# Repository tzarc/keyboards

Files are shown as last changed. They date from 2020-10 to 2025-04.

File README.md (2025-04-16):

# @tzarc's Keyboards.

Here you'll find the design files for @tzarc's custom keyboard designs.

Since February 2024, licenses have changed from GPL3 to CERN-OHL-S.

## Djinn

The [Djinn](Djinn/README.md) is a 64-key split keyboard -- dual 4x7 with a 4-key thumb cluster. It also has a 5-way tactile switch under the thumb.

Djinn

## Ghoul

The [Ghoul](Ghoul/README.md) is a Planck-like development board for QMK, using SparkFun MicroMod for hot-swap MCU capability in a `2x4x5=40` layout with encoder and RGB OLED, per-key RGB.

Ghoul

## Kobold

The [Kobold](Kobold/README.md) is an ortho 4x4 macropad, as a replacement for a bm16s with modern hardware.

Kobold

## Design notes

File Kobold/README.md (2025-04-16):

# Kobold

4x4 macropad running QMK, in the same form factor as a bm16s. Non-standard Choc key spacing.

STM32G431, North-facing RGB, SPI NOR Flash, voltage and current measurement, direct pin matrix, reset to bootloader by holding top 4 keys.

Kobold

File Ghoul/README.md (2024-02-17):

# Ghoul

Planck-like development board for QMK, using SparkFun MicroMod for hot-swap MCU capability.

`2x4x5=40` layout with encoder and RGB OLED, per-key RGB.

Has hardware support for MicroSD, SPI EEPROM, SPI NOR Flash.

Uses 74HC589 SPI Shift Registers for key matrix.

Ghoul

Micromod

Top

Bottom

(images generated by [tracespace](https://tracespace.io/))

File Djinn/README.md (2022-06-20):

# Djinn Split Keyboard

The Djinn is a 64-key split keyboard -- dual 4x7 with a 4-key thumb cluster. It also has a 5-way tactile switch under the thumb.

Djinn

Extravagance-wise, it's got audio, encoder support, per-key RGB and RGB underglow... and a 240x320 LCD. And for the safety conscious, it has ESD protection, transient voltage suppression, and polarity protection on both the USB connector as well as the split transport connector (USB-C for rev2+, TRS for rev1).

It also runs [QMK Firmware](https://qmk.fm/)!

Building can be done with:

```
make tzarc/djinn/rev2:default
```

## Rev2a

BOM: [Click](Rev2a/Djinn-BOM.md)

Fixes:

* 5-way tactile moved further away from thumb row
* Different current limiters used for RGB that are actually functional in the required range

Djinn Rev2a PCB

Djinn Rev2a PCB

Djinn Rev2a Built

## Rev1

BOM: [Click](Rev1/Djinn-BOM.md)

Djinn

Issues:

* RGB current limiting has been reported to be problematic on Rev1 -- some builds have reported non-functional RGB without overriding the code to enable 1500mA limits
  * Measurements taken do not show that the RGB pulls anything close to 1500mA, unknown if there's a manufacturing issue or component selection issue
* 5-way tactile switch is too close to the thumb row in Rev1 and pressing in the down direction can't be achieved very easily

Djinn Rev1 PCB
Djinn Rev1 PCB
Djinn Rev1 PCB

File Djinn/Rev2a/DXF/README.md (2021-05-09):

# DXF Files

**! WARNING !**

**! WARNING !**

**! WARNING !**

These files are untested. They may be x1000 too large or x1000 too small.

Use at your own risk.

3D-print these if you have a printer available, before investing in carbon fibre plates or brass bases. Check geometry and sizing before spending cash.

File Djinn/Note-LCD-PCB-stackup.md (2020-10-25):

# Total Stackup

## LCD Stackup

- 3mm acrylic (or 3mm spacer)
- 4mm spacer
- 1.6mm LCD PCB
- 12mm spacer
- 1.6mm logic PCB
- **Total = 22.2mm**

| 12mm + 5mm screw     |
|----------------------|
| 3mm acrylic          |
| 4mm spacer           |
| 1.6mm LCD PCB        |
| 3.4mm of 12mm spacer |
| **= 12mm screw**     |
| 3.4mm of 12mm spacer |
| 1.6mm logic PCB      |
| **= 5mm screw**      |

---

## Plate + Logic board + Base stackup

- 1.6mm plate PCB
- 0.5mm washer
- 3mm spacer
- 1.6mm logic PCB
- 3mm spacer
- 1.6mm base PCB
- **Total = 11.3mm**

| 8mm + 3mm screw     |
|---------------------|
| 1.6mm plate PCB     |
| 3mm spacer          |
| 0.5mm washer        |
| 1.6mm logic PCB     |
| 1.3mm of 3mm spacer |
| **= 8mm screw**     |
| 1.4mm of 3mm spacer |
| 1.6mm base PCB      |
| **= 3mm screw**     |

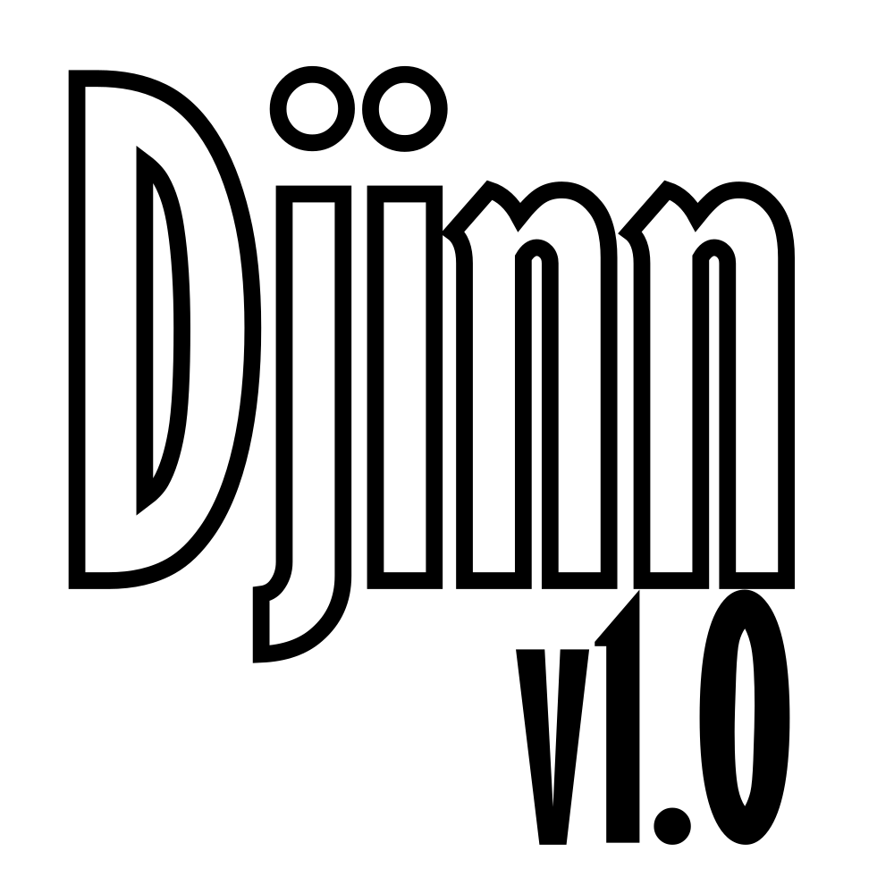
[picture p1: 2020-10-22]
Djinn/Rev1/DjinnNameVer.png

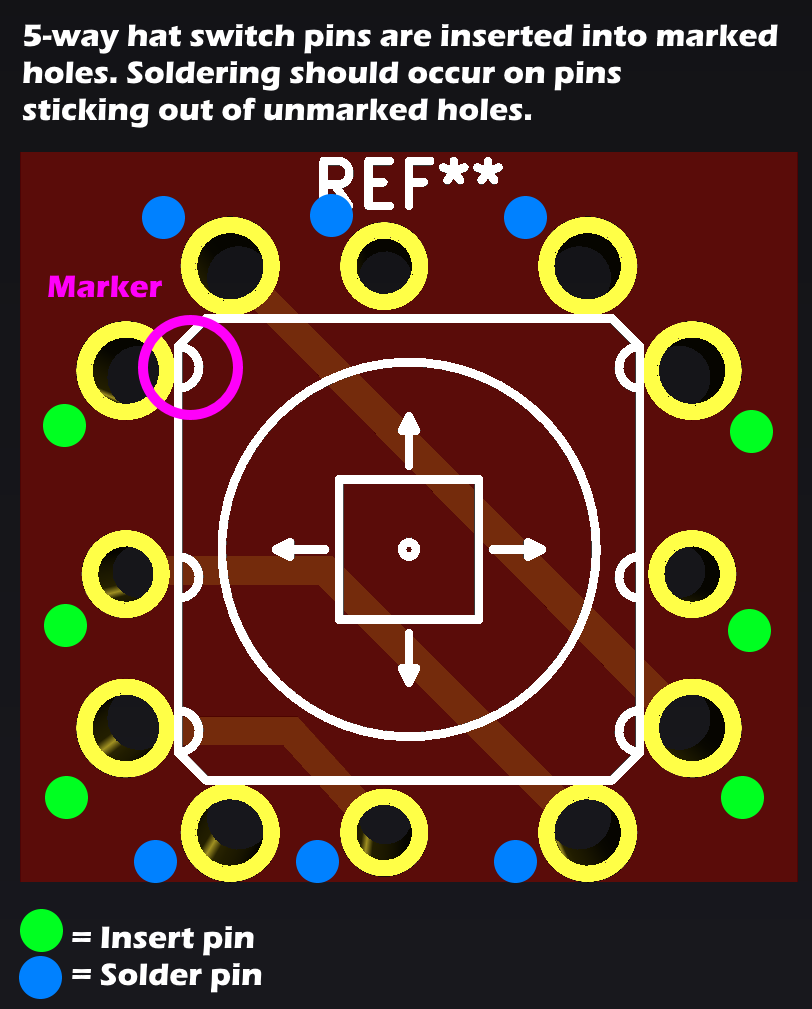
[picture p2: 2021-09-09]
Djinn/Rev2a/reversible-kicad/reversible-kicad-footprints/5Way-K1-1506DN-01.png

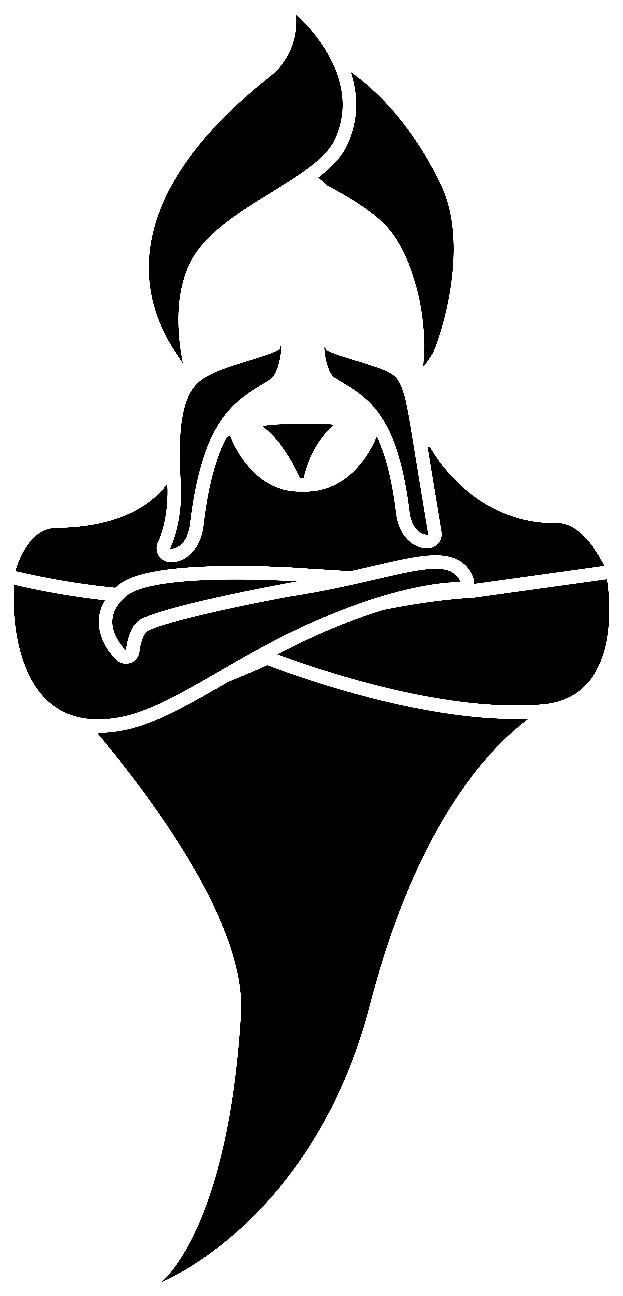
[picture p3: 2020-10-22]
Djinn/Rev1/Djinn.png

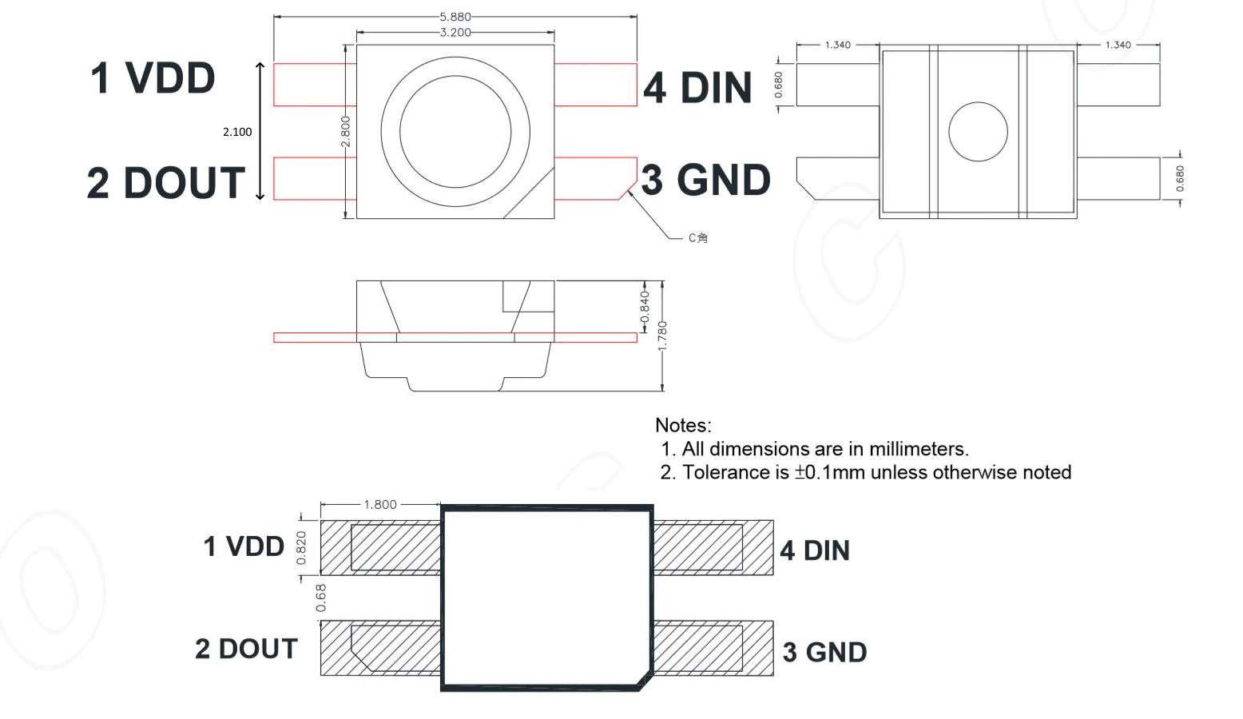
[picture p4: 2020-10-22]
Djinn/Rev1/reversible-kicad/datasheets/RGB-LED_SK6812Mini-E.png

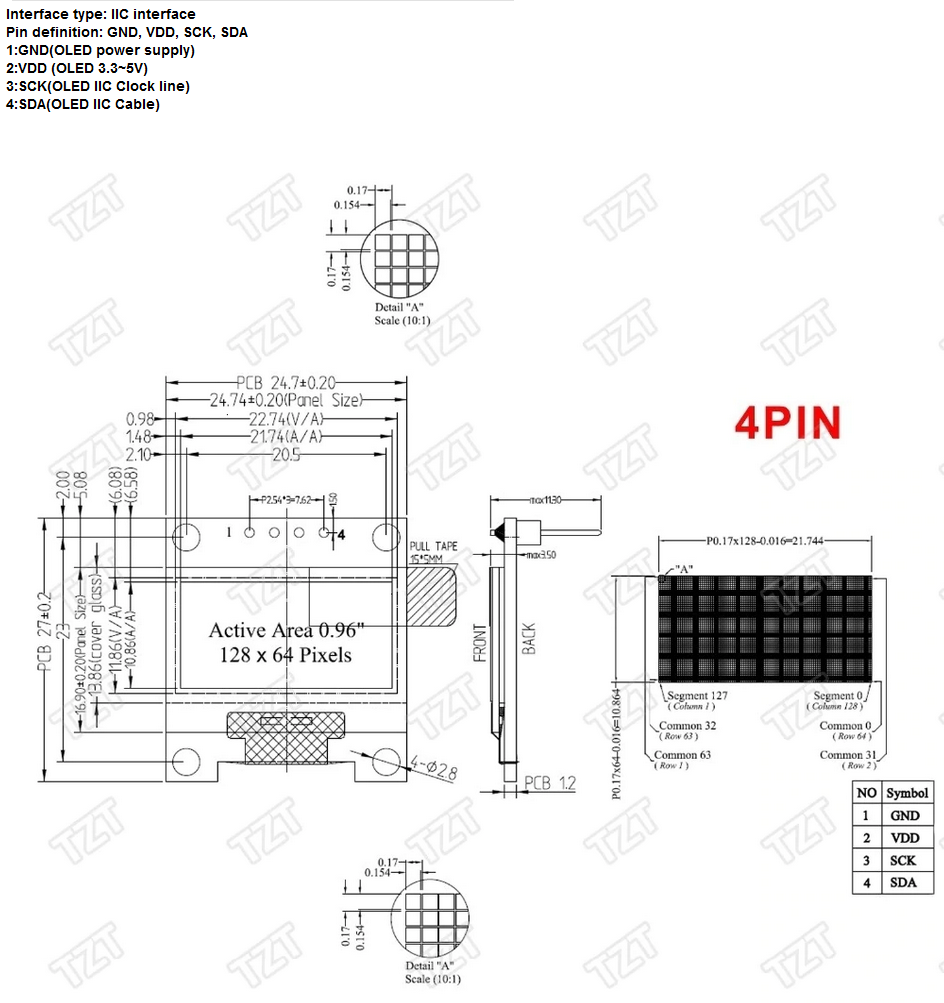
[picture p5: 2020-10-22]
Djinn/Rev1/reversible-kicad/datasheets/OLED-SSD1306-128x64.png

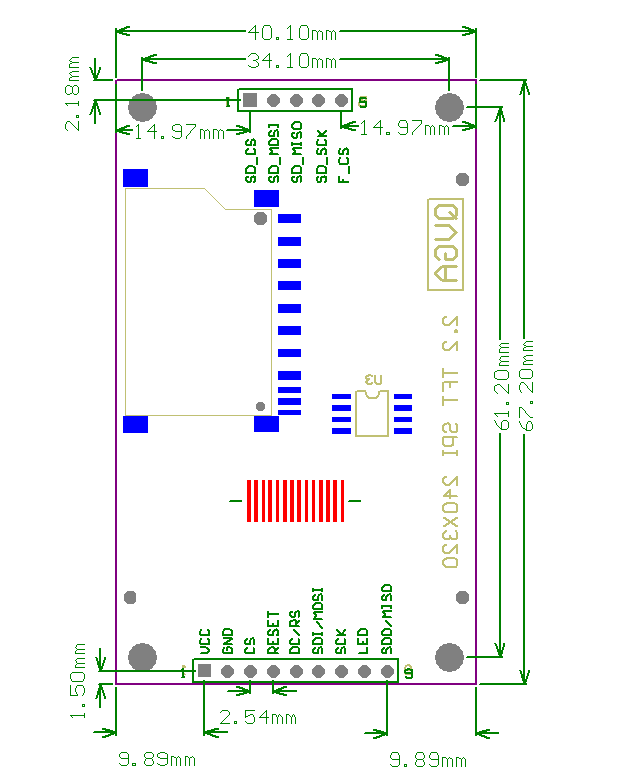
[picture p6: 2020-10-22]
Djinn/Rev1/reversible-kicad/datasheets/LCD-ILI9341-2.2in.png

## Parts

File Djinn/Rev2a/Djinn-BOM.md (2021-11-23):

# Djinn Rev2a BOM

## PCB Manufacture

I've had some reports that JLCPCB have thrown on a $15.20 USD extra charge due to too many instances of routing.

I (@tzarc) wasn't charged, but there are now reports on Discord that JLCPCB are charging extra.

If you've been given an extra charge, feel free to ask them why you've been charged more than others with the same design... and let @tzarc know so we can keep track of whether other PCB manufacturers should be recommended instead of JLCPCB.

## Build Notes

**There are two resistors that are used to determine whether the PCB is a left-hand or a right-hand board -- R23 and R25. Populate only one; R23 for a left-hand board, R25 for a right-hand board.**

During the build, the connectors for the USB-C, and the LCD 1x09 connector **need to be mounted on the side opposite to the rest of the surface-mount components**. For ease of the build, it's best to populate and solder these onto the board last. The 1x09 LCD connector can also be soldered with the LCD screwed into the board with standoffs, in order to ensure proper alignment.

RGB underglow LEDs can be soldered on either side of the board.

Most "jellybean" components can be swapped out for whichever you've got available -- 100nF capacitors are so ubiquitous that there's no need to buy this specific part. Any other 0805 100nF capacitor will likely suffice.

The "Connector (ST-Link)" **is optional** and is not required -- this is a debugging port for an ST-Link. If you choose to do so, it can be mounted with the pins straddling the edge of the PCB.

The "IC (SPI FLASH)" **is not required** -- this is for future QMK development and the Djinn has no requirement for it to be on the board.

There is a few sets of solder bridges that need to be filled in to get certain aspects working:

* LCD_Left / LCD_Right -- 9 separate solder bridges that connect the LCD connector to the normal lines required to actually drive the LCD. You'll note that these are populated in the same location on both sides of the board -- only the side being built should have the solder bridges filled in. Left-hand should have LCD_Left soldered, right-hand should have LCD_Right soldered.

## Components listing

| Type | Count (Total) | Count (Per PCB) | Value | Footprint | Part Number | Link |
|---|---|---|---|---|---|---|
| Capacitor (MLCC) | 30 | 15 | 100nF | 0805 | CL21F104ZBCNNNC | https://lcsc.com/product-detail/Multilayer-Ceramic-Capacitors-MLCC-SMD-SMT_Samsung-Electro-Mechanics-CL21F104ZBCNNNC_C1760.html |
| Capacitor (MLCC) | 8 | 4 | 4.7uF | 0805 | CL21A475KAQNNNE | https://lcsc.com/product-detail/Multilayer-Ceramic-Capacitors-MLCC-SMD-SMT_Samsung-Electro-Mechanics-CL21A475KAQNNNE_C1779.html |
| Capacitor (Tantalum) | 16 | 8 | 100uF | 6032 | F931C107KCC | https://lcsc.com/product-detail/Tantalum-Capacitors_AVX-F931C107KCC_C273664.html |
| Resistor | 36 | 18 | 9.1k 1% | 0805 | RK73H2ATTD9101F | https://lcsc.com/product-detail/Chip-Resistor-Surface-Mount_KOA-Speer-Elec-RK73H2ATTD9101F_C317276.html |
| Resistor | 22 | 11 | 68k 1% | 0805 | AC0805FR-0768KL | https://lcsc.com/product-detail/Chip-Resistor-Surface-Mount_YAGEO-AC0805FR-0768KL_C228958.html |
| Resistor | 6 | 3 | 120ohm 1% | 0805 | WR08X1200FTL | https://lcsc.com/product-detail/Chip-Resistor-Surface-Mount_Walsin-Tech-Corp-WR08X1200FTL_C163960.html |
| Diode (Signal) | 80 | 40 | 1N4148 | SOD-123FL | 1N4148WL | https://lcsc.com/product-detail/Switching-Diode_Shandong-Jingdao-Microelectronics-1N4148WL_C108804.html |
| Diode (TVS Protection)  | 4 | 2 | SMF5.0CA | SOD-123FL | SMF5.0CA | https://lcsc.com/product-detail/TVS_MDD-Microdiode-Electronics-SMF5-0CA_C364279.html |
| IC (SPI FRAM) | 2 | 1 | 64kbit/8kB | SOIC-8 | MB85RS64PNF-G-JNERE1 | https://lcsc.com/product-detail/FRAM_FUJITSU-MB85RS64PNF-G-JNERE1_C8741.html |
| IC (SPI FLASH) | 2 (skip) | 1 (skip) | - | SOIC-8W | W25Q32JVSSIQ | Not required for Djinn, do not populate, used for future QMK development |
| IC (Voltage Regulator)  | 2 | 1 | 3.3V | SOT-23-5  | AP2127K-3.3TRG1 | https://lcsc.com/product-detail/Dropout-Regulators-LDO_Diodes-Incorporated-AP2127K-3-3TRG1_C156285.html |
| IC (Op-Amp) | 2 | 1 | - | SOT-23-5  | LMV321B-TR or LMV321 | https://lcsc.com/product-detail/Low-Power-OpAmps_3PEAK-LMV321B-TR_C248567.html or https://lcsc.com/product-detail/Low-Power-OpAmps_IDCHIP-LMV321_C395459.html |
| IC (Current Limiter) | 4 | 2 | - | SOT-23-6  | TPS2553DBVR or AP2553W6-7 | https://lcsc.com/product-detail/PMIC-Power-Distribution-Switches_Texas-Instruments-TPS2553DBVR_C55266.html or https://lcsc.com/product-detail/PMIC-Power-Distribution-Switches_Diodes-Incorporated_AP2553W6-7_Diodes-Incorporated-AP2553W6-7_C212302.html |
| Diode (ESD Protection)  | 4 | 2 | - | SOT-23-6  | AZC199-04S.R7G or SRV0504 | https://lcsc.com/product-detail/TVS_AMAZING-AZC199-04S-R7G_C356821.html or https://lcsc.com/product-detail/TVS_Leiditech-SRV0504_C384888.html |
| IC (MCU) | 2 | 1 | - | LQFP-64 | STM32G474RET6 | https://au.mouser.com/ProductDetail/STMicroelectronics/STM32G474RET6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 |
| Resettable Fuse | 2 | 1 | 3.0A | 1206 | MF-NSMF150-2 | https://lcsc.com/product-detail/PTC-Resettable-Fuses_BOURNS-MF-NSMF150-2_C89655.html |
| Resettable Fuse | 2 | 1 | 1.5A | 1206 | MF-NSMF075-2 | https://lcsc.com/product-detail/PTC-Resettable-Fuses_BOURNS-MF-NSMF075-2_C89653.html |
| Switch (Hotswap Socket) | 64 | 32 | - | - | Kailh Hotswap | https://www.aliexpress.com/item/32903471019.html |
| Switch (5-way Tactile)  | 2 | 1 | - | 10x10mm | K1-1506DN-01 | https://lcsc.com/product-detail/5-way-Tactile-Switches_Korean-Hroparts-Elec-K1-1506DN-01_C145911.html |
| Switch (Cap) | 2 | 1 | - | - | 6JBLK | https://lcsc.com/product-detail/Switch-accessories-or-Caps_E-Switch-6JBLK_C273384.html |
| Switch (Rotary Encoder) | 2 | 1 | - | - | EC11N1525404 | https://lcsc.com/product-detail/Coded-Rotary-Switches_ALPS-Electric-EC11N1525404_C470748.html |
| Connector (USB-C) | 4 | 2 | - | - | TYPE-C-31-M-12 | https://lcsc.com/product-detail/USB-Connectors_Korean-Hroparts-Elec-TYPE-C-31-M-12_C165948.html |
| Inductor | 26 | 13 | 100ohm @ 100MHz 4A | 0805 | MPZ2012S101AT000 | https://lcsc.com/product-detail/Ferrite-Beads_TDK-MPZ2012S101AT000_C15957.html |
| Connector (LCD) | 2 | 1 | - | 1x09 | C39576 | https://lcsc.com/product-detail/Pin-Header-Female-Header_BOOMELE-Boom-Precision-Elec-C39576_C39576.html |
| Piezo Buzzer | 2 | 1 | - | 16x16mm | KLJ-1625 | https://lcsc.com/product-detail/Buzzers_KELIKING-KLJ-1625_C201041.html |
| Switch (Microswitch) | 2 | 1 | - | - | TSA451G50-250 | https://lcsc.com/product-detail/Tactile-Switches_BRIGHT-TSA451G50-250_C294483.html |
| RGB LED | 86 | 43 | - | 6028 | SK6812Mini-E | https://www.aliexpress.com/item/4000475685852.html |
| MOSFET | 8 | 4 | - | SOT-23-3  | AO3401A | https://lcsc.com/product-detail/MOSFET_UMW-Youtai-Semiconductor-Co-Ltd-AO3401A_C347476.html |
| MOSFET | 4 | 2 | - | SOT-23-3  | 2N7002 | https://lcsc.com/product-detail/MOSFET_MDD-Microdiode-Electronics-2N7002_C472906.html |
| Transistor (Pre-biased) | 2 | 1 | - | SOT-23-3  | MMUN2133LT1G | https://lcsc.com/product-detail/Digital-Transistors_ON-Semiconductor-MMUN2133LT1G_C86182.html |
| Transistor (Pre-biased) | 2 | 1 | - | SOT-23-3  | MMUN2233LT1G | https://lcsc.com/product-detail/Transistors-NPN-PNP_ON-Semiconductor-MMUN2233LT1G_C86932.html |
| Connector (ST-Link) | 2 (optional)  | 1 (optional) | - | 2x05 | MTF185-205SY3 | https://lcsc.com/product-detail/Pin-Header-Female-Header_MINTRON-MTF185-205SY3_C358738.html |
| LCD | 2 | 1 | - | 1x09 | 2.2" No Touch | https://www.aliexpress.com/item/4000219159401.html |

## Fasteners / Hardware

| Type | Count (Total) | Count (Per side) | Model | Link |
|---|---|---|---|---|
| Knob (Rotary Encoder) | 2 | 1 | 25x15.5x6mm  | https://www.aliexpress.com/item/32802067713.html |
| Screw | 26 | 13 | M3x3 D7x0.7  | https://www.aliexpress.com/item/32998579840.html |
| Screw | 26 | 13 | M3x8 D7x0.7  | https://www.aliexpress.com/item/32998579840.html |
| Screw | 8 | 4 | M3x12 D7x0.7 | https://www.aliexpress.com/item/32998579840.html |
| Screw | 8 | 4 | M3x5 D7x0.7  | https://www.aliexpress.com/item/32998579840.html |
| Standoff | 52 (or 60) | 26 (or 30) | M3x3x4.2 | https://www.aliexpress.com/item/4000153040875.html |
| Standoff | 8 | 4 | M3x12x4.2 | https://www.aliexpress.com/item/4000153040875.html |
| Standoff | 8 | 4 | M3x4x4.2 | https://www.aliexpress.com/item/4000153040875.html |
| Washer | 26 | 13 | M3 | https://www.aliexpress.com/item/33000267180.html |

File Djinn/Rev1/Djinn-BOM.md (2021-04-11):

# Djinn Rev1 BOM

## Build Notes

During the build, the connectors for the USB-C, the TRS jack, and the LCD 1x09 connector **need to be mounted on the side opposite to the rest of the surface-mount components**. For ease of the build, it's best to populate and solder these onto the board last. The 1x09 LCD connector can also be soldered with the LCD screwed into the board with standoffs, in order to ensure proper alignment.

Most "jellybean" components can be swapped out for whichever you've got available -- 100nF capacitors are so ubiquitous that there's no need to buy this specific part. Any other 0805 100nF capacitor will likely suffice.

The "IC (Current Limiter)" chip has two alternatives that perform the same function, with the same pinout, and are drop-in replacements of each other. Depending on stock levels at LCSC, one might not be available (as was the case when the Djinn was designed), so either can be used. Please only purchase one type -- you don't need both. These chips do have poor performance at low currents, i.e. the standard <500mA USB current range. As a result, if you push the LEDs too hard (full white, for instance) they'll flicker and sometimes "brown out" -- this is 100% intentional and is not a sign that something is wrong with your build -- this is a safety mechanism to prevent pulling too much current from the USB port. Sane limits have already been set in firmware to prevent over-current scenarios. In future, once the firmware matures, the limit will be dynamically controlled based on the USB-C power delivery state -- this is not yet implemented, but the hardware has been designed to do so.

The "Connector (ST-Link)" **is optional** and is not required -- this is a debugging port for an ST-Link. If you choose to do so, it can be mounted with the pins straddling the edge of the PCB.

There are a few sets of solder bridges that need to be filled in to get certain aspects working:

* USB-C CC Line solder bridges (solder none or one pair only):
    * (Optional) 5.1k -- 2 separate solder bridges that connect 5.1k resistors to the USB-C CC lines in order to "ask" for 3.0A from the upstream port. This is not guaranteed to automatically allow 3.0A of current, and the firmware will eventually deal with this correctly.
    * (Optional) USBPD -- 2 separate solder bridges that connect the MCU to the USB-C CC lines in order to enable USBPD functionality. This is not yet built into the firmware and for all intents and purposes should not be assumed to work. Leave these unsoldered unless you know exactly what you're doing.
    * If neither of the above pairs of solder bridges have been soldered, the Djinn will work in standard USB2.0 mode without attempting to run at a higher current than 500mA.
* LCD_Left / LCD_Right -- 9 separate solder bridges that connect the LCD connector to the normal lines required to actually drive the LCD. You'll note that these are populated in the same location on both sides of the board -- only the side being built should have the solder bridges filled in. Left-hand should have LCD_Left soldered, right-hand should have LCD_Right soldered.

## Components listing

| Type | Count (Total) | Count (Per PCB) | Value | Footprint | Part Number | Link |
|---|---|---|---|---|---|---|
| Capacitor (MLCC) | 110 | 55 | 100nF | 0805 | CL21F104ZBCNNNC | https://lcsc.com/product-detail/Multilayer-Ceramic-Capacitors-MLCC-SMD-SMT_Samsung-Electro-Mechanics-CL21F104ZBCNNNC_C1760.html |
| Capacitor (MLCC) | 2 | 1 | 4.7nF | 0805 | CC0805KRX7R9BB472 | https://lcsc.com/product-detail/Multilayer-Ceramic-Capacitors-MLCC-SMD-SMT_YAGEO-CC0805KRX7R9BB472_C107153.html |
| Capacitor (Tantalum) | 8 | 4 | 10uF | 3216 | TC212A106K016Y | https://lcsc.com/product-detail/Tantalum-Capacitors_Sunlord-TC212A106K016Y_C108529.html |
| Connector (LCD) | 2 | 1 | - | 1x09 | C39576 | https://lcsc.com/product-detail/Pin-Header-Female-Header_BOOMELE-Boom-Precision-Elec-C39576_C39576.html |
| Connector (ST-Link, *optional*) | 2 | 1 | - | 1x09 | MTF185-205SY3 | https://lcsc.com/product-detail/Pin-Header-Female-Header_MINTRON-MTF185-205SY3_C358738.html |
| Connector (TRS) | 2 | 1 | - | - | PJ-3136-B | https://lcsc.com/product-detail/Audio-Video-Connectors_XKB-Connectivity-PJ-3136-B_C381131.html |
| Connector (USB-C) | 2 | 1 | - | - | TYPE-C-31-M-12 | https://lcsc.com/product-detail/USB-Connectors_Korean-Hroparts-Elec-TYPE-C-31-M-12_C165948.html |
| Diode (ESD Protection) | 4 | 2 | USBLC6-4SC6 | SOT-23-6  | USBLC6-4SC6 | https://lcsc.com/product-detail/Diodes-ESD_STMicroelectronics_USBLC6-4SC6_USBLC6-4SC6_C111212.html |
| Diode (Schottky) | 2 | 1 | SS34 | SOD-123FL | DSS34 | https://lcsc.com/product-detail/Schottky-Barrier-Diodes-SBD_BORN-DSS34_C511866.html |
| Diode (Signal) | 80 | 40 | 1N4148 | SOD-123FL | 1N4148WL | https://lcsc.com/product-detail/Switching-Diode_Shandong-Jingdao-Microelectronics-1N4148WL_C108804.html |
| Diode (TVS Protection) | 4 | 2 | SMF5.0CA | SOD-123FL | SMF5.0CA | https://lcsc.com/product-detail/TVS_MDD-Microdiode-Electronics-SMF5-0CA_C364279.html |
| IC (Current Limiter) | 2 | 1 | - | SOT-23-5  | MT9700 *or* DIO7002  | https://lcsc.com/product-detail/PMIC-Power-Distribution-Switches_MT9700_C89855.html *or* https://lcsc.com/product-detail/PMIC-Power-Distribution-Switches_DIOO-DIO7002AST5_C403840.html |
| IC (MCU) | 2 | 1 | - | LQFP-64 | STM32G474RET6 | https://au.mouser.com/ProductDetail/STMicroelectronics/STM32G474RET6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 |
| IC (SPI FRAM) | 2 | 1 | 64kbit/8kB  | SOIC-8 | MB85RS64PNF-G-JNERE1 | https://lcsc.com/product-detail/FRAM_FUJITSU-MB85RS64PNF-G-JNERE1_C8741.html |
| IC (Voltage Regulator) | 2 | 1 | 3.3V | SOT-23-5  | AP2127K-3.3TRG1 | https://lcsc.com/product-detail/Dropout-Regulators-LDO_Diodes-Incorporated-AP2127K-3-3TRG1_C156285.html |
| LCD | 2 | 1 | - | 1x09 | 2.2" No Touch | https://www.aliexpress.com/item/4000219159401.html |
| MOSFET | 6 | 3 | - | SOT-23-3  | AO3401A | https://lcsc.com/product-detail/MOSFET_UMW-Youtai-Semiconductor-Co-Ltd-AO3401A_C347476.html |
| Piezo Buzzer | 2 | 1 | - | 16x16mm | KLJ-1625 | https://lcsc.com/product-detail/Buzzers_KELIKING-KLJ-1625_C201041.html |
| Resettable Fuse | 2 | 1 | 1.5A | 1206 | MF-NSMF075-2 | https://lcsc.com/product-detail/PTC-Resettable-Fuses_BOURNS-MF-NSMF075-2_C89653.html |
| Resettable Fuse | 2 | 1 | 3.0A | 1206 | MF-NSMF150-2 | https://lcsc.com/product-detail/PTC-Resettable-Fuses_BOURNS-MF-NSMF150-2_C89655.html |
| Resistor | 2 | 1 | 1.5k 1% | 0805 | RC0805FR-071K5L | https://lcsc.com/product-detail/Chip-Resistor-Surface-Mount_YAGEO-RC0805FR-071K5L_C114555.html |
| Resistor | 2 | 1 | 100k 1% | 0805 | 0805W8F1003T5E | https://lcsc.com/product-detail/Chip-Resistor-Surface-Mount_UNI-ROYAL-Uniroyal-Elec-0805W8F1003T5E_C149504.html |
| Resistor | 2 | 1 | 13.7k 1% | 0805 | CR0805F81372G | https://lcsc.com/product-detail/Chip-Resistor-Surface-Mount_LIZ-Elec-CR0805F81372G_C101466.html |
| Resistor | 2 | 1 | 52.3k 1% | 0805 | WR08X5232FTL | https://lcsc.com/product-detail/Chip-Resistor-Surface-Mount_Walsin-Tech-Corp-WR08X5232FTL_C170927.html |
| Resistor | 20 | 10 | 9.1k 1% | 0805 | RK73H2ATTD9101F | https://lcsc.com/product-detail/Chip-Resistor-Surface-Mount_KOA-Speer-Elec-RK73H2ATTD9101F_C317276.html |
| Resistor | 4 | 2 | 120ohm 1% | 0805 | WR08X1200FTL | https://lcsc.com/product-detail/Chip-Resistor-Surface-Mount_Walsin-Tech-Corp-WR08X1200FTL_C163960.html |
| Resistor | 4 | 2 | 1M 1% | 0805 | 0805W8F1004T5E | https://lcsc.com/product-detail/Chip-Resistor-Surface-Mount_UNI-ROYAL-Uniroyal-Elec-0805W8F1004T5E_C17514.html |
| Resistor | 8 | 4 | 5.1k 1% | 0805 | 0805W8F5101T5E | https://lcsc.com/product-detail/Chip-Resistor-Surface-Mount_UNI-ROYAL-Uniroyal-Elec-0805W8F5101T5E_C27834.html |
| RGB LED | 84 | 42 | - | 6028 | SK6812Mini-E | https://www.aliexpress.com/item/4000475685852.html |
| Switch (5-way Tactile) | 2 | 1 | - | 10x10mm | K1-1506DN-01 | https://lcsc.com/product-detail/5-way-Tactile-Switches_Korean-Hroparts-Elec-K1-1506DN-01_C145911.html |
| Switch (Cap) | 2 | 1 | - | - | 6JBLK | https://lcsc.com/product-detail/Switch-accessories-or-Caps_E-Switch-6JBLK_C273384.html |
| Switch (Hotswap Socket) | 64 | 32 | - | - | Kailh Hotswap | https://www.aliexpress.com/item/32903471019.html |
| Switch (Microswitch) | 2 | 1 | - | - | TSA451G50-250 | https://lcsc.com/product-detail/Tactile-Switches_BRIGHT-TSA451G50-250_C294483.html |
| Switch (Rotary Encoder) | 2 | 1 | - | - | EC11N1525404 | https://lcsc.com/product-detail/Coded-Rotary-Switches_ALPS-Electric-EC11N1525404_C470748.html |
| Transistor (Pre-biased) | 2 | 1 | - | SOT-23-3  | MMUN2133LT1G | https://lcsc.com/product-detail/Digital-Transistors_ON-Semiconductor-MMUN2133LT1G_C86182.html |
| Transistor (Pre-biased) | 6 | 3 | - | SOT-23-3  | MMUN2233LT1G | https://lcsc.com/product-detail/Transistors-NPN-PNP_ON-Semiconductor-MMUN2233LT1G_C86932.html |

## Fasteners / Hardware

| Type | Count (Total) | Count (Per side) | Model | Link |
|---|---|---|---|---|
| Knob (Rotary Encoder) | 2 | 1 | 25x15.5x6mm  | https://www.aliexpress.com/item/32802067713.html |
| Screw | 26 | 13 | M3x3 D7x0.7  | https://www.aliexpress.com/item/32998579840.html |
| Screw | 26 | 13 | M3x8 D7x0.7  | https://www.aliexpress.com/item/32998579840.html |
| Screw | 8 | 4 | M3x12 D7x0.7 | https://www.aliexpress.com/item/32998579840.html |
| Screw | 8 | 4 | M3x5 D7x0.7  | https://www.aliexpress.com/item/32998579840.html |
| Standoff | 52 (or 60) | 26 (or 30) | M3x3x4.2 | https://www.aliexpress.com/item/4000153040875.html |
| Standoff | 8 | 4 | M3x12x4.2 | https://www.aliexpress.com/item/4000153040875.html |
| Standoff | 8 | 4 | M3x4x4.2 | https://www.aliexpress.com/item/4000153040875.html |
| Washer | 26 | 13 | M3 | https://www.aliexpress.com/item/33000267180.html |

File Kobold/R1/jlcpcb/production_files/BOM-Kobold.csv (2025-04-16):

Comment | Designator | Footprint | LCSC | Quantity
1k | R10,R13 | R_0402_1005Metric | C11702 | 2
AP2552FDC-7 | U3 | WDFN-6_L2.0-W2.0-P0.65-BL-EP-1 | C150475 | 1
100n | C1,C10,C11,C12,C13,C14,C15,C16,C17,C18,C19,C2,C20,C21,C22,C23,C24,C25,C26,C27,C3 | C_0402_1005Metric | C1525 | 21
TYPE-C-31-M-12 | J1 | USB_C_Receptacle_HRO_TYPE-C-31-M-12 | C165948 | 1
INA180A4 | U5 | SOT-23-5_L3.0-W1.7-P0.95-LS2.8-BR | C188337 | 1
1N4148 | D18 | D_SOD-323 | C2128 | 1
75k | R2,R4,R5,R9 | R_0603_1608Metric | C23242 | 4
4.7u | C4,C5,C6,C7,C8,C9 | C_0402_1005Metric | C23733 | 6
10k | R1,R11,R12,R6,R7,R8 | R_0402_1005Metric | C25744 | 6
SN74LVC1G14DRL | U1,U11,U13,U15,U16,U2,U9 | SOT-553-5_L1.6-W1.2-P0.50-LS1.6-BL | C2682052 | 7
SN74AHC1G08DRL | U10,U12,U14 | SOT-553-5_L1.6-W1.2-P0.50-LS1.6-BL | C352951 | 3
RGB | D1,D10,D11,D12,D13,D14,D15,D16,D2,D3,D4,D5,D6,D7,D8,D9 | LED_choc_6028R | C5149201 | 16
STM32G431CBU6 | U7 | QFN-48-1EP_7x7mm_P0.5mm_EP5.6x5.6mm | C529356 | 1
XC6206PxxxMR | U4 | SOT-23-3 | C5446 | 1
H5VL10B | D17 | D_SOD-882 | C7420372 | 1
H5VU25U | U6 | DFN2510-10_L2.5-W1.0-P0.50-BL | C7420374 | 1
BOOT0 | SW17,SW18,SW19 | SW-SMD_4P-L3.0-W2.6-P1.80-LS3.4-TL | C778132 | 3
0.05R | R3 | R_1206_3216Metric | C912768 | 1
W25Q128JVSIQ | U8 | SOIC-8_5.3x5.3mm_P1.27mm | C97521 | 1
Push | SW14 | SW_choc_v1_HS_CPG135001S30_1u |  | 1
Push | SW11 | SW_choc_v1_HS_CPG135001S30_1u |  | 1
Push | SW13 | SW_choc_v1_HS_CPG135001S30_1u |  | 1
Push | SW5 | SW_choc_v1_HS_CPG135001S30_1u |  | 1
Push | SW10 | SW_choc_v1_HS_CPG135001S30_1u |  | 1
Push | SW16 | SW_choc_v1_HS_CPG135001S30_1u |  | 1
Push | SW6 | SW_choc_v1_HS_CPG135001S30_1u |  | 1
Push | SW7 | SW_choc_v1_HS_CPG135001S30_1u |  | 1
Push | SW12 | SW_choc_v1_HS_CPG135001S30_1u |  | 1
Push | SW2 | SW_choc_v1_HS_CPG135001S30_1u |  | 1
Push | SW8 | SW_choc_v1_HS_CPG135001S30_1u |  | 1
Push | SW4 | SW_choc_v1_HS_CPG135001S30_1u |  | 1
Push | SW15 | SW_choc_v1_HS_CPG135001S30_1u |  | 1
Push | SW9 | SW_choc_v1_HS_CPG135001S30_1u |  | 1
Push | SW3 | SW_choc_v1_HS_CPG135001S30_1u |  | 1
Push | SW1 | SW_choc_v1_HS_CPG135001S30_1u |  | 1

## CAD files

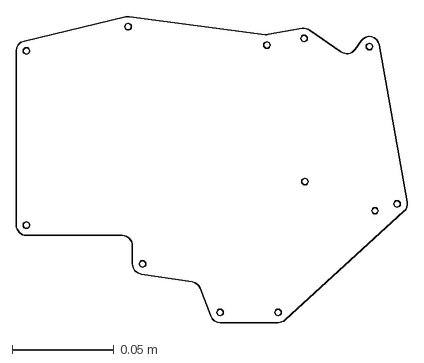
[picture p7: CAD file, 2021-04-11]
Djinn/Rev2a/DXF/base_pcb.dxf
0.193 x 0.151 m

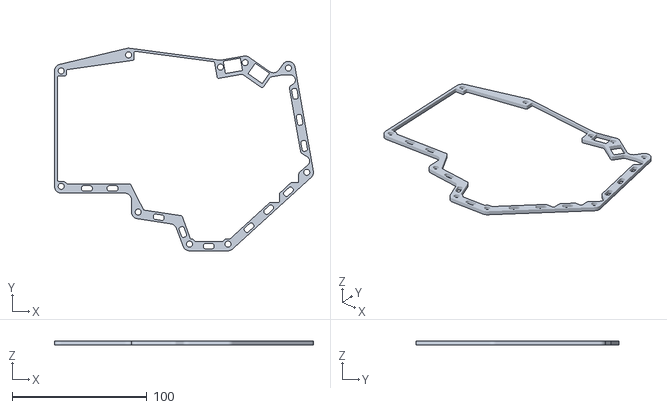
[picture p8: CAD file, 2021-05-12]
Djinn/Rev2a/STL/Djinn_BottomSpacer_3mm.stl
192.3 x 150.5 x 3.00

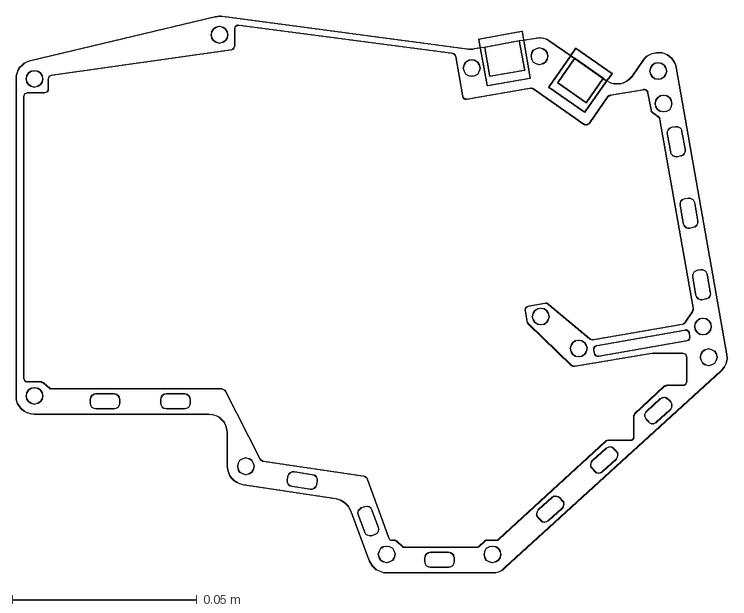
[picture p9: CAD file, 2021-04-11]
Rev2a/DXF/spacer.dxf
0.193 x 0.151 m

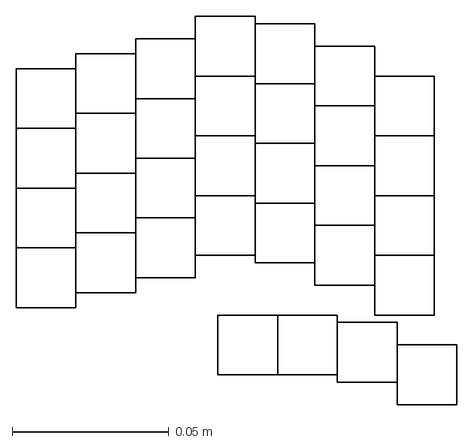
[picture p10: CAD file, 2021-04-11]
Djinn/Rev2a/DXF/keyswitch_outlines.dxf
0.14 x 0.124 m

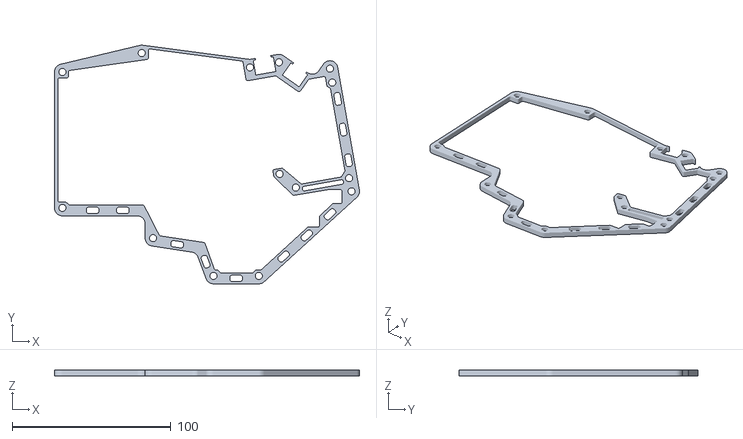
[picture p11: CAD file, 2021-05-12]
Djinn/Rev2a/STL/Djinn_TopSpacer_3.5mm.stl
192.3 x 150.5 x 3.50

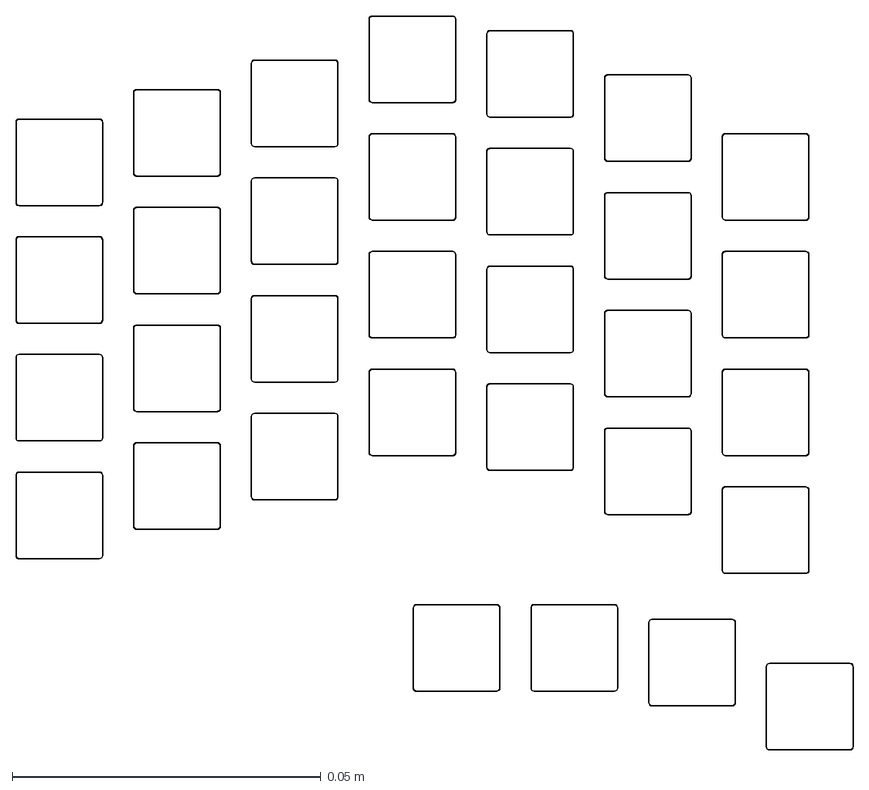
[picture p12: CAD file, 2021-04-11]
Djinn/Rev2a/DXF/keyswitch_cuts.dxf
0.135 x 0.119 m

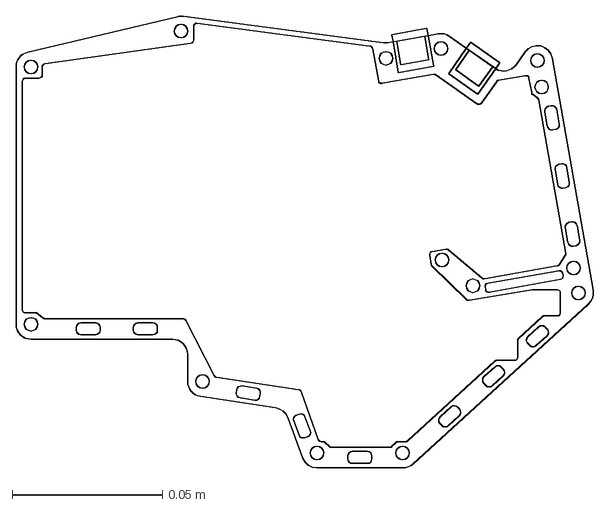
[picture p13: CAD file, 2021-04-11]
Djinn/Rev2a/DXF/acrylic_spacer.dxf
0.193 x 0.151 m

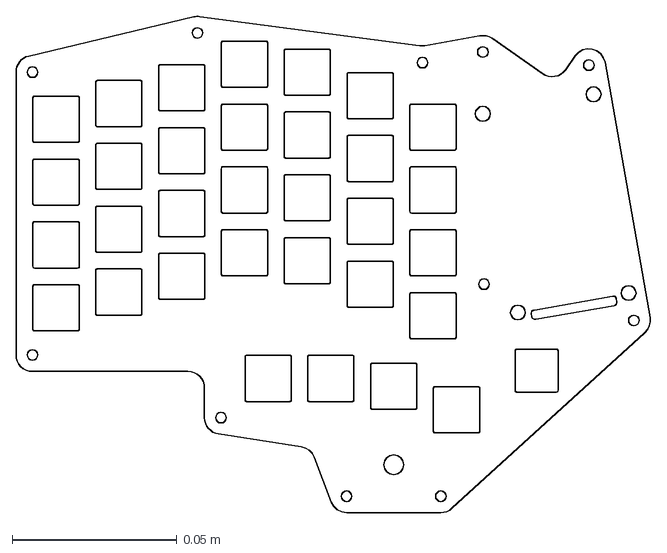
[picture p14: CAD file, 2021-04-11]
Djinn/Rev2a/DXF/plate_pcb.dxf
0.193 x 0.151 m

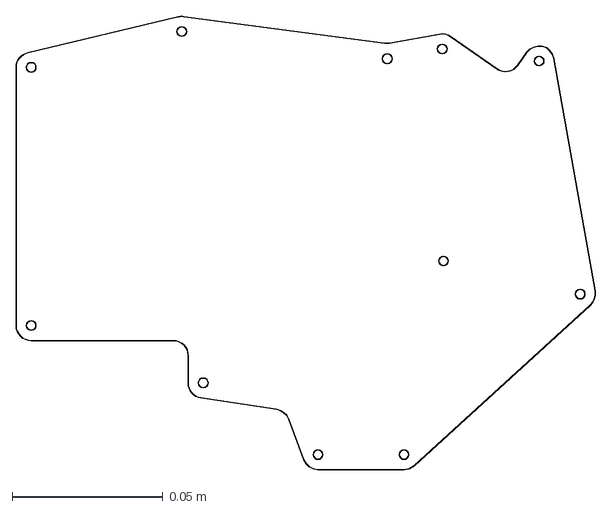
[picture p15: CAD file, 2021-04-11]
Djinn/Rev2a/DXF/outline+drills.dxf
0.193 x 0.151 m

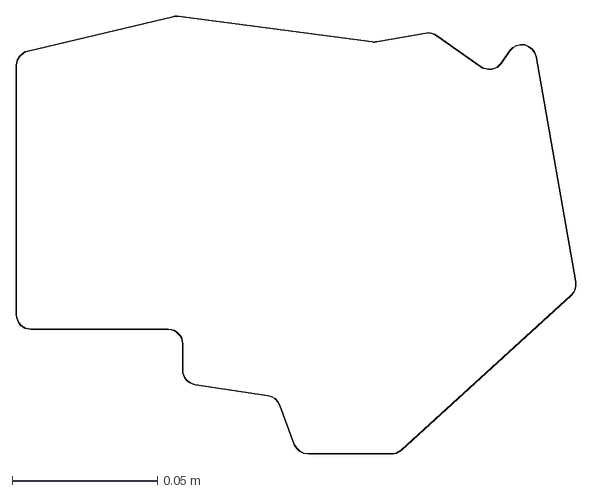
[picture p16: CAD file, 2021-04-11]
Djinn/Rev2a/DXF/outline.dxf
0.193 x 0.151 m

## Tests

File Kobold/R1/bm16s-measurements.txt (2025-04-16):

Horizontal

15.3
21.6
Horiz 1-1 = 18.5

52.4
58.7
Horiz 1-4 = 55.5

18.5*3 = 55.5
so 18.5mm spacing

Vertical

14.4
20.7
Vert 1-1 = 17.5

49.3
55.6
Vert 1-4 = 52.5

17.5*3 = 52.5
so 17.5mm spacing

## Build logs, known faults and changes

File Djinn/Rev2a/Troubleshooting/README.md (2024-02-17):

# Troubleshooting

This should hopefully help troubleshoot issues with getting the Djinn up and running.

## Initial steps

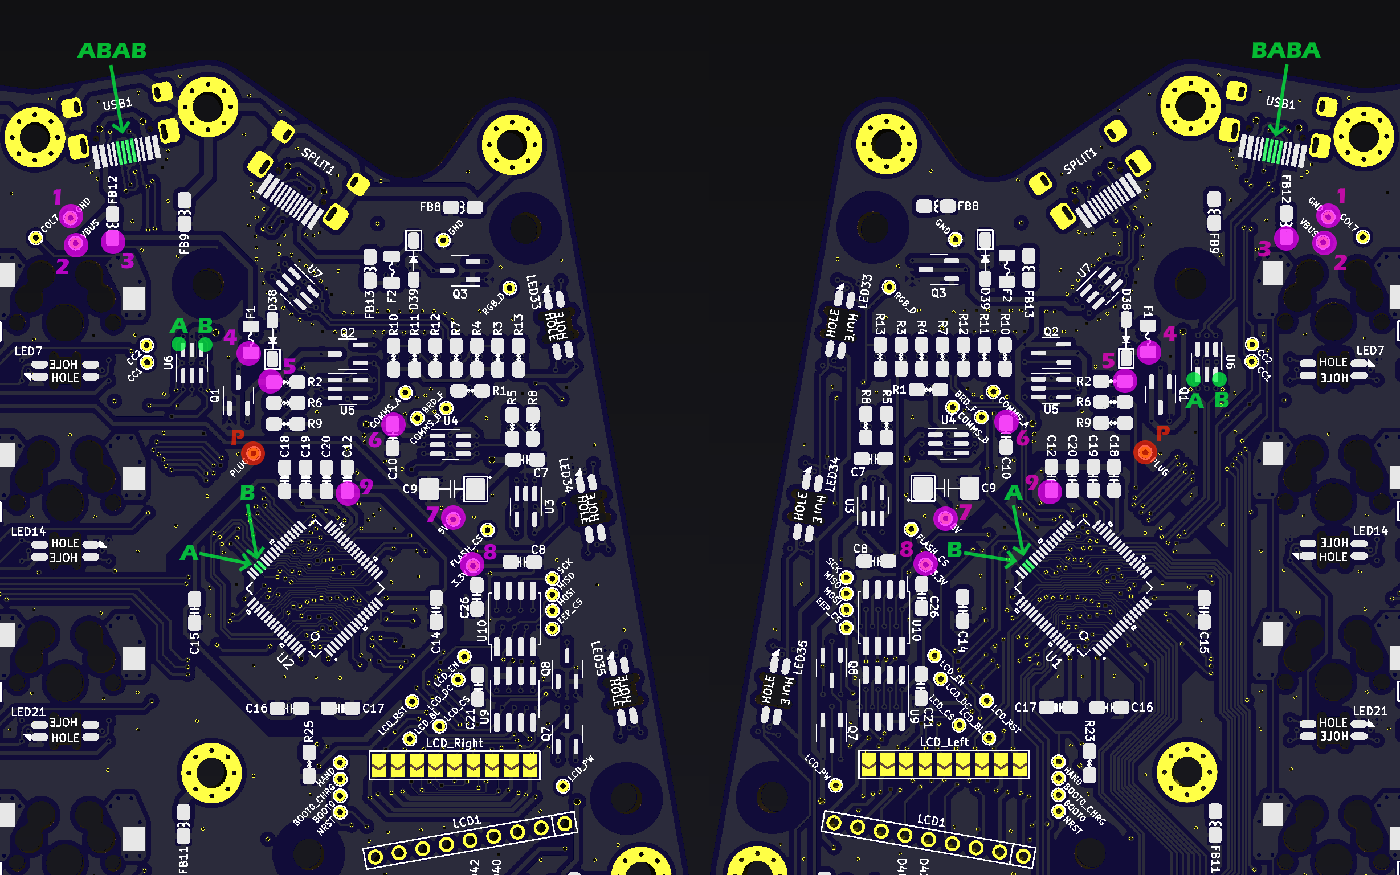
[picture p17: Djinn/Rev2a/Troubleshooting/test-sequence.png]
Test Sequence


- Check that 1 & 2 aren't shorted together
- Check that the A's and B's aren't shorted together
- Check that the A's are all connected
- Check that the B's are all connected
- Measure 1-2 with multimeter, should be 5V
- Measure 1-3 with multimeter, should be 5V
- Measure 1-4 with multimeter, should be 5V
- Measure 1-5 with multimeter, should be 5V
- Measure 1-6 with multimeter, should be 5V
- Measure 1-7 with multimeter, should be 5V
- Measure 1-8 with multimeter, should be 3.3V
- Measure 1-9 with multimeter, should be 3.3V
- Measure 1-P with multimeter, should be 3.3V if connected to USB, 0V if not connected to USB

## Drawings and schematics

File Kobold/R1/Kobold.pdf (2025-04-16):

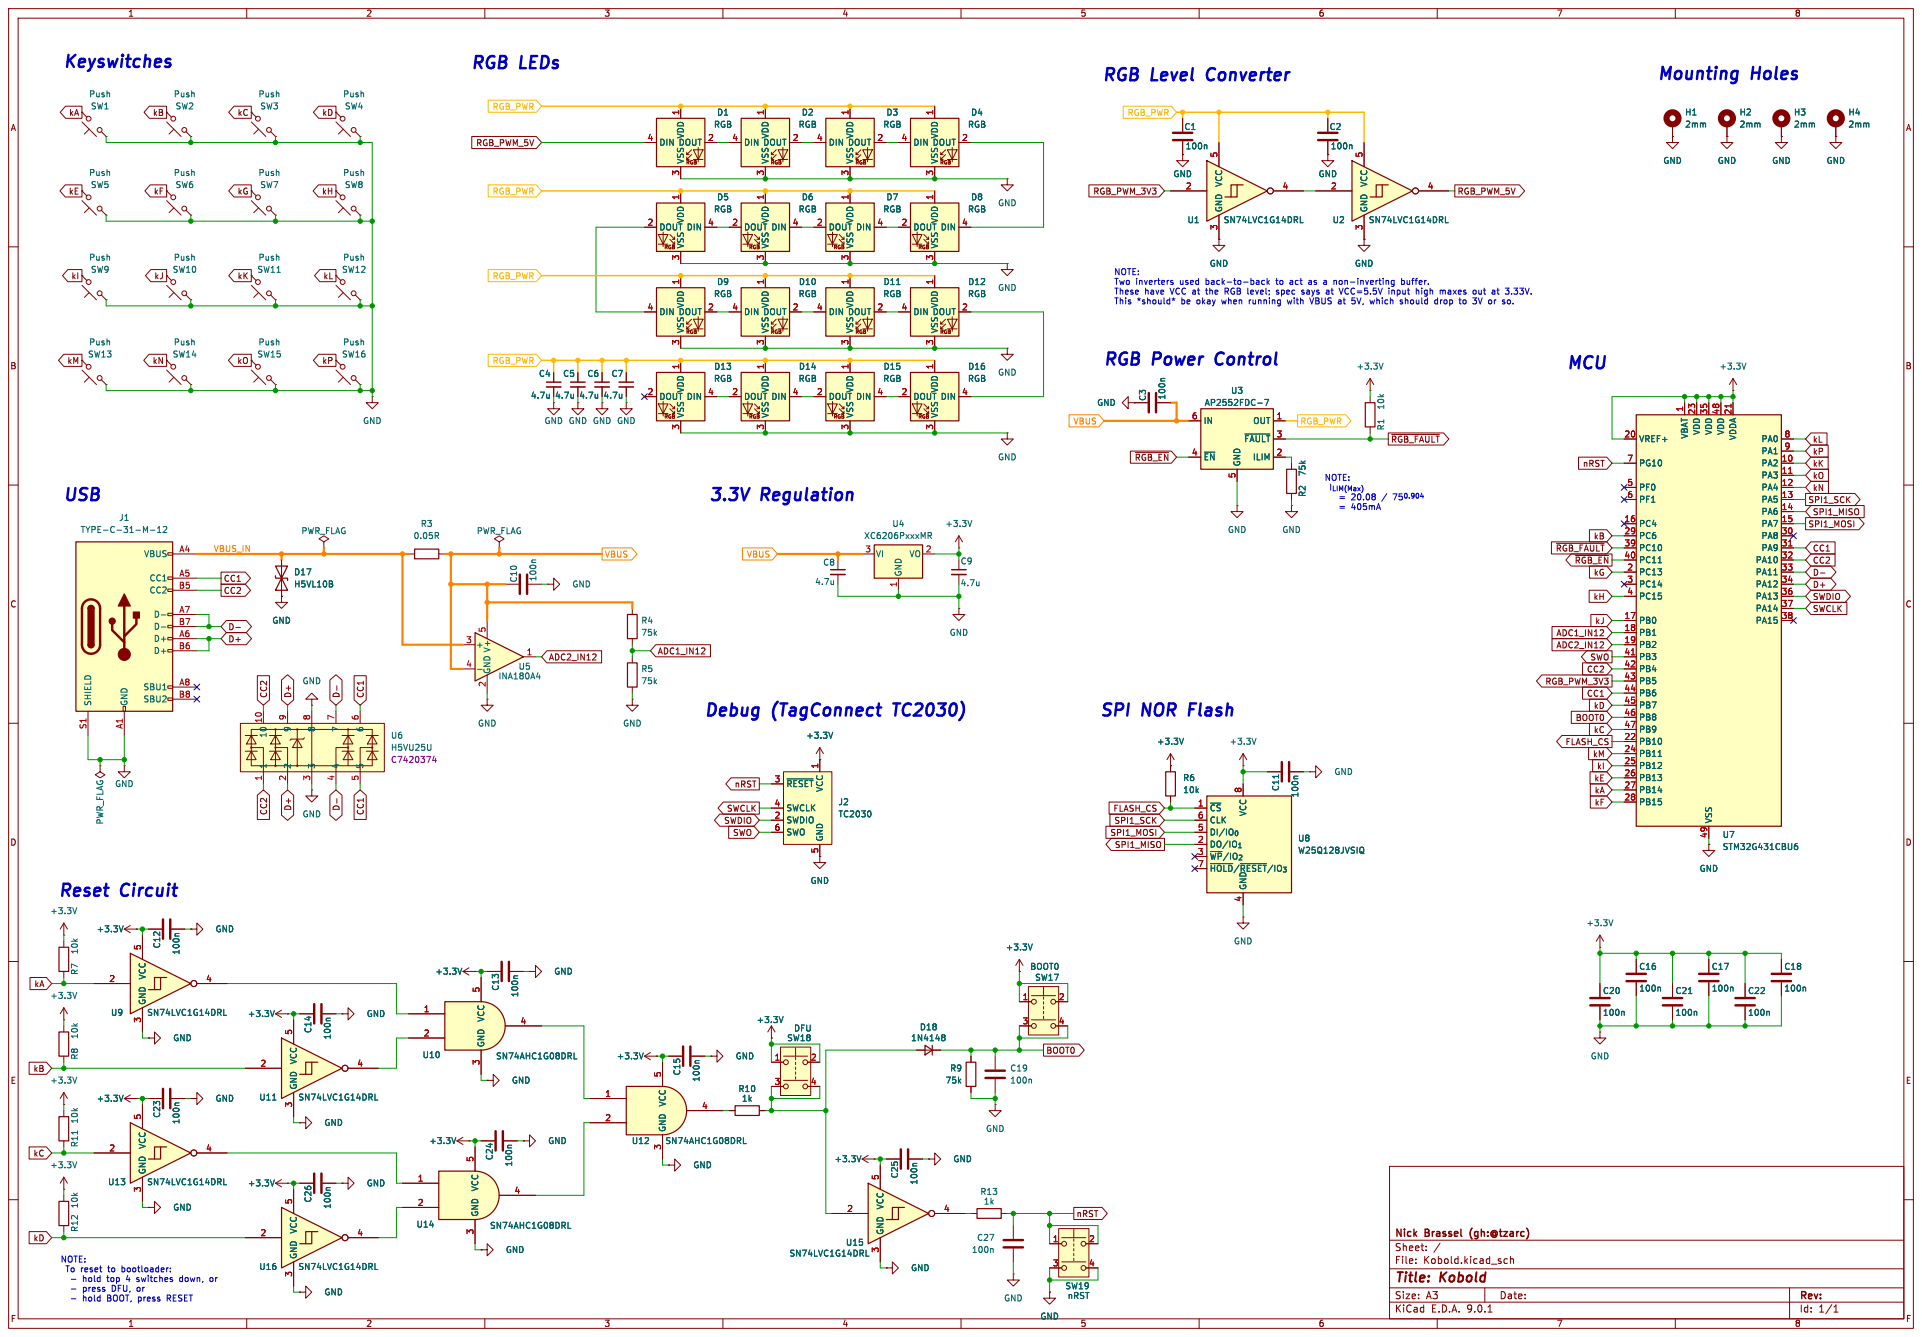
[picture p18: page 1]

I_{LIM(Max)} = 20.08 / 75^{0.904} = 405mA RGB LEDs

3 DOUT 2 D1 RGB DIN 4 VDD

3 DOUT 2 D2 RGB DIN 4 VDD

3 DOUT 2 D3 RGB DIN 4 VDD

3 DOUT 2 D4 RGB DIN 4 VDD

3 DOUT 2 D10 RGB DIN 4 VDD

3 DOUT 2 D12 RGB DIN 4 VDD

3 DOUT 2 D6 RGB DIN VDD 4

3 DOUT 2 D5 RGB DIN VDD 4

3 DOUT 2 D7 RGB DIN VDD 4

3 DOUT 2 D9 RGB DIN 4 VDD

3 DOUT 2 D11 RGB DIN 4 VDD

3 DOUT 2 D12 RGB GND GND GND

3 DOUT 2 D13 RGB DIN VDD 4

1 VDD 23 VDD 35 VSS 49 VDD 48 VDDA 21 PA0

Reset Circuit NOTE: To reset to bootloader: - hold top 4 switches down, or

5 ~{RESET} 3 SWCLK 4 SWDIO 2 SWO 6
nRST SWO

5 ~{RESET} 3 SWCLK 4 SWDIO 2 SWO 6 GND

- press DFU, or
- hold BOOT, press RESET

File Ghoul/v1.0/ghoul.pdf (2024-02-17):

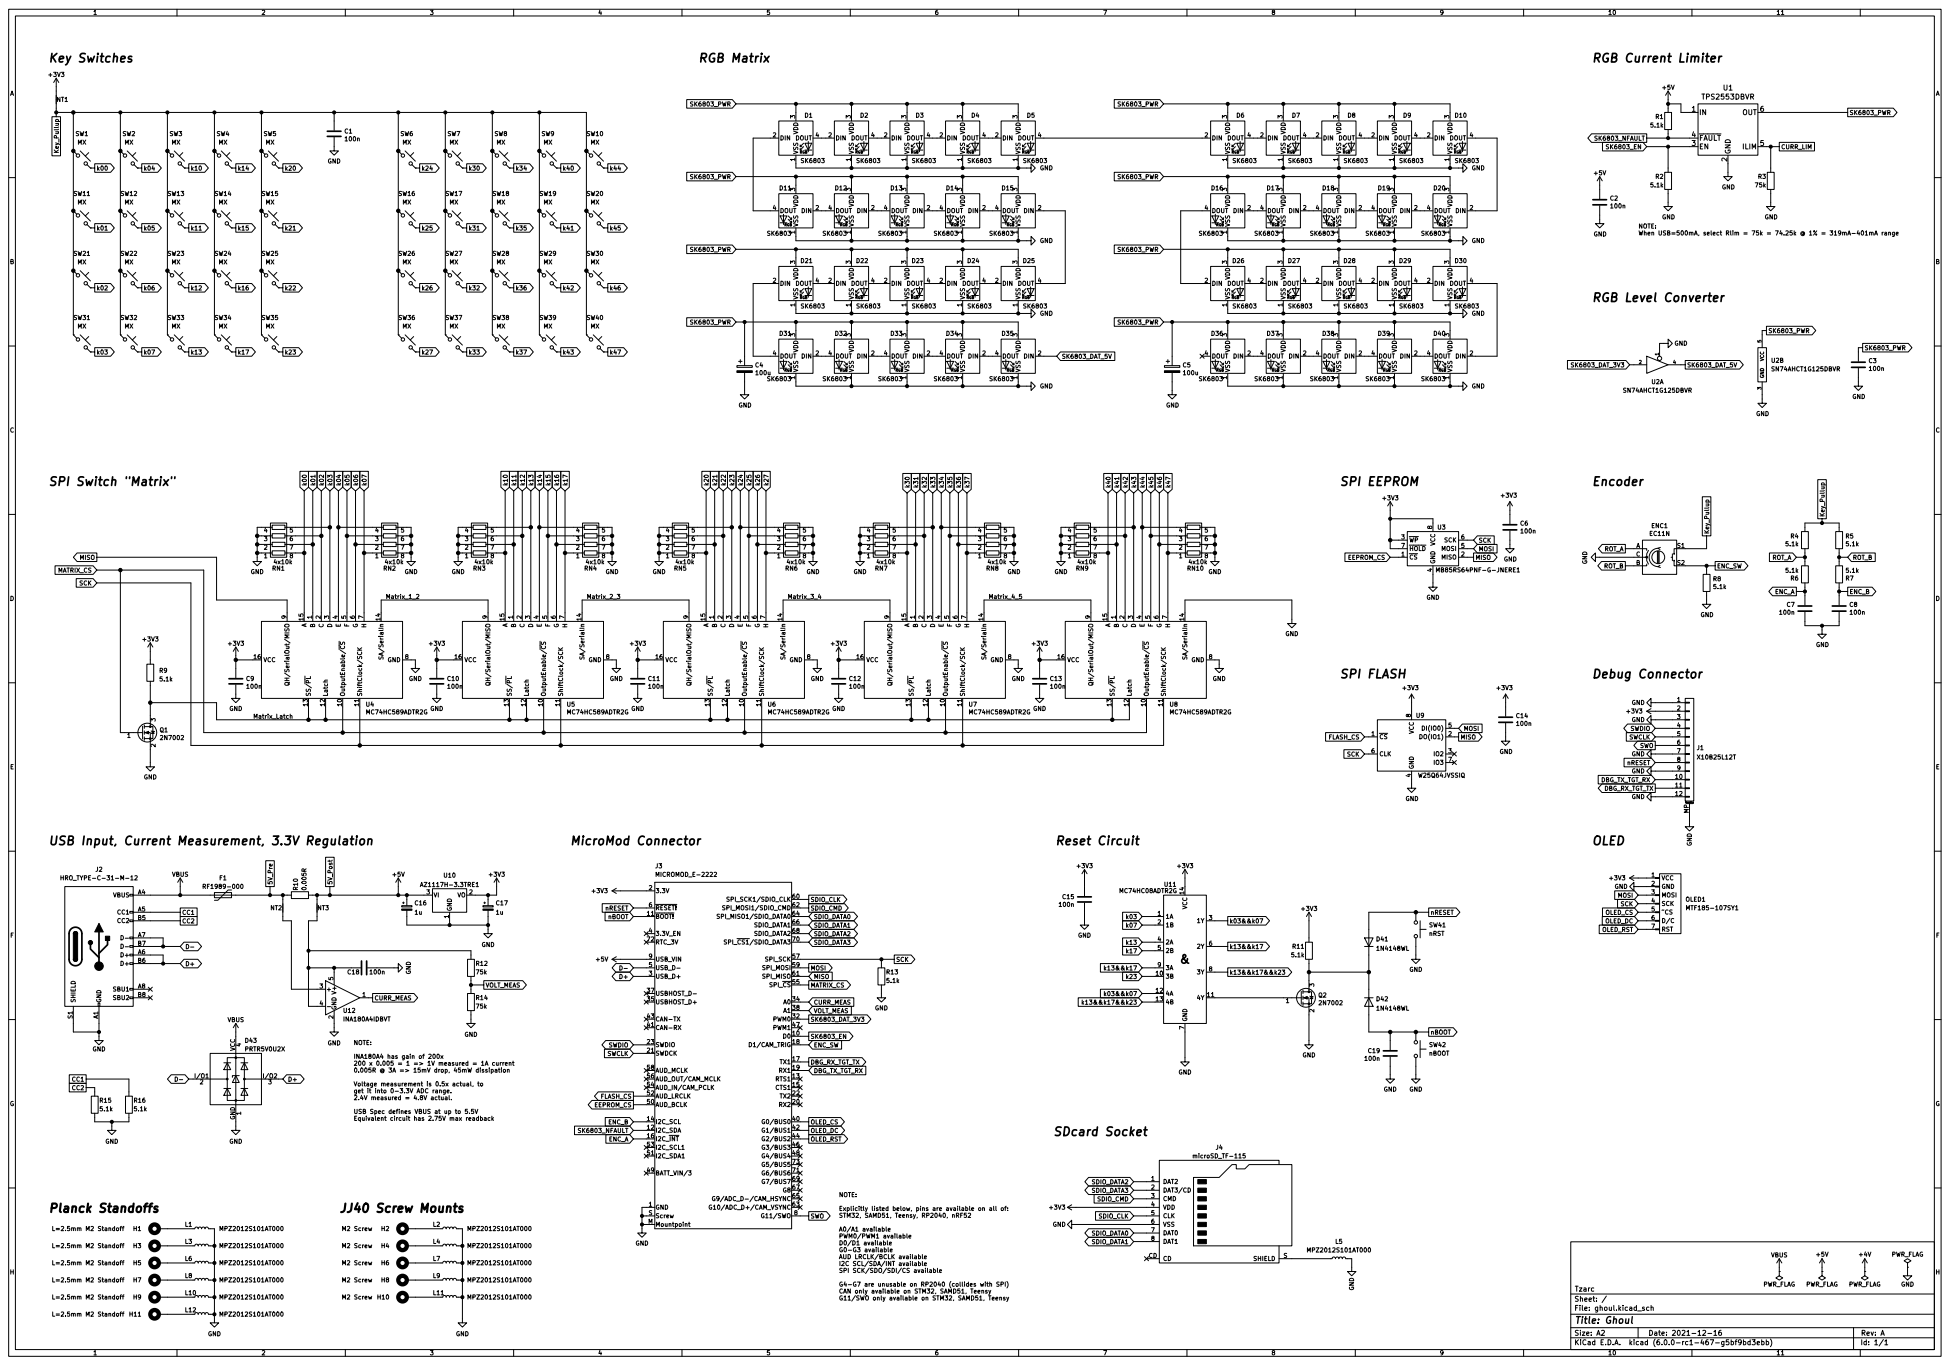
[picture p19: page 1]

3 DOUT 4 D2 SK6803 VSS RGB 1 DIN 2 VDD

3 DOUT 4 D5 SK6803 VSS RGB 1 DIN 2 VDD

3 DOUT 4 D4 SK6803 VSS RGB 1 DIN 2 VDD

3 DOUT 4 D25 SK6803GND VSS RGB 1 DIN 2 VDD

3 DOUT 4 D15 SK6803 GND VSS RGB 1 DIN 2 VDD

3 DOUT 4 D13 SK6803 VSS RGB 1 DIN 2 VDD

NOTE: When USB=500mA, select Rlim = 75k = 74.25k @ 1% = 319mA-401mA range

3 DOUT 4 D23 SK6803 GND VSS RGB 1 DIN 2 VDD

1 OutputEnable/~{CS} 10 ShiftClock/SCK 11 Latch 12 SS/~{PL} 13 SA/SerialIn 14 A 15 VCC 16 C

7 GND 8 QH/SerialOut/MISO

USB Input, Current Measurement, 3.3V Regulation

INA180A4 has gain of 200x 200 x 0.005 = 1 => 1V measured = 1A current 0.005R @ 3A => 15mV drop, 45mW dissipation

Voltage measurement is 0.5x actual, to
get it into 0-3.3V ADC range. 2.4V measured = 4.8V actual. USB Spec defines VBUS at up to 5.5V

Equivalent circuit has 2.75V max readback

NOTE: Explicitly listed below, pins are available on all of:

STM32, SAMD51, Teensy, RP2040, nRF52 A0/A1 available PWM0/PWM1 available D0/D1 available G0-G3 available AUD LRCLK/BCLK available

I2C SCL/SDA/INT available SPI SCK/SDO/SDI/CS available G4-G7 are unusable on RP2040 (collides with SPI)

CAN only available on STM32, SAMD51, Teensy
G11/SWO only available on STM32, SAMD51, Teensy

File: ghoul.kicad_sch Sheet: / Tzarc

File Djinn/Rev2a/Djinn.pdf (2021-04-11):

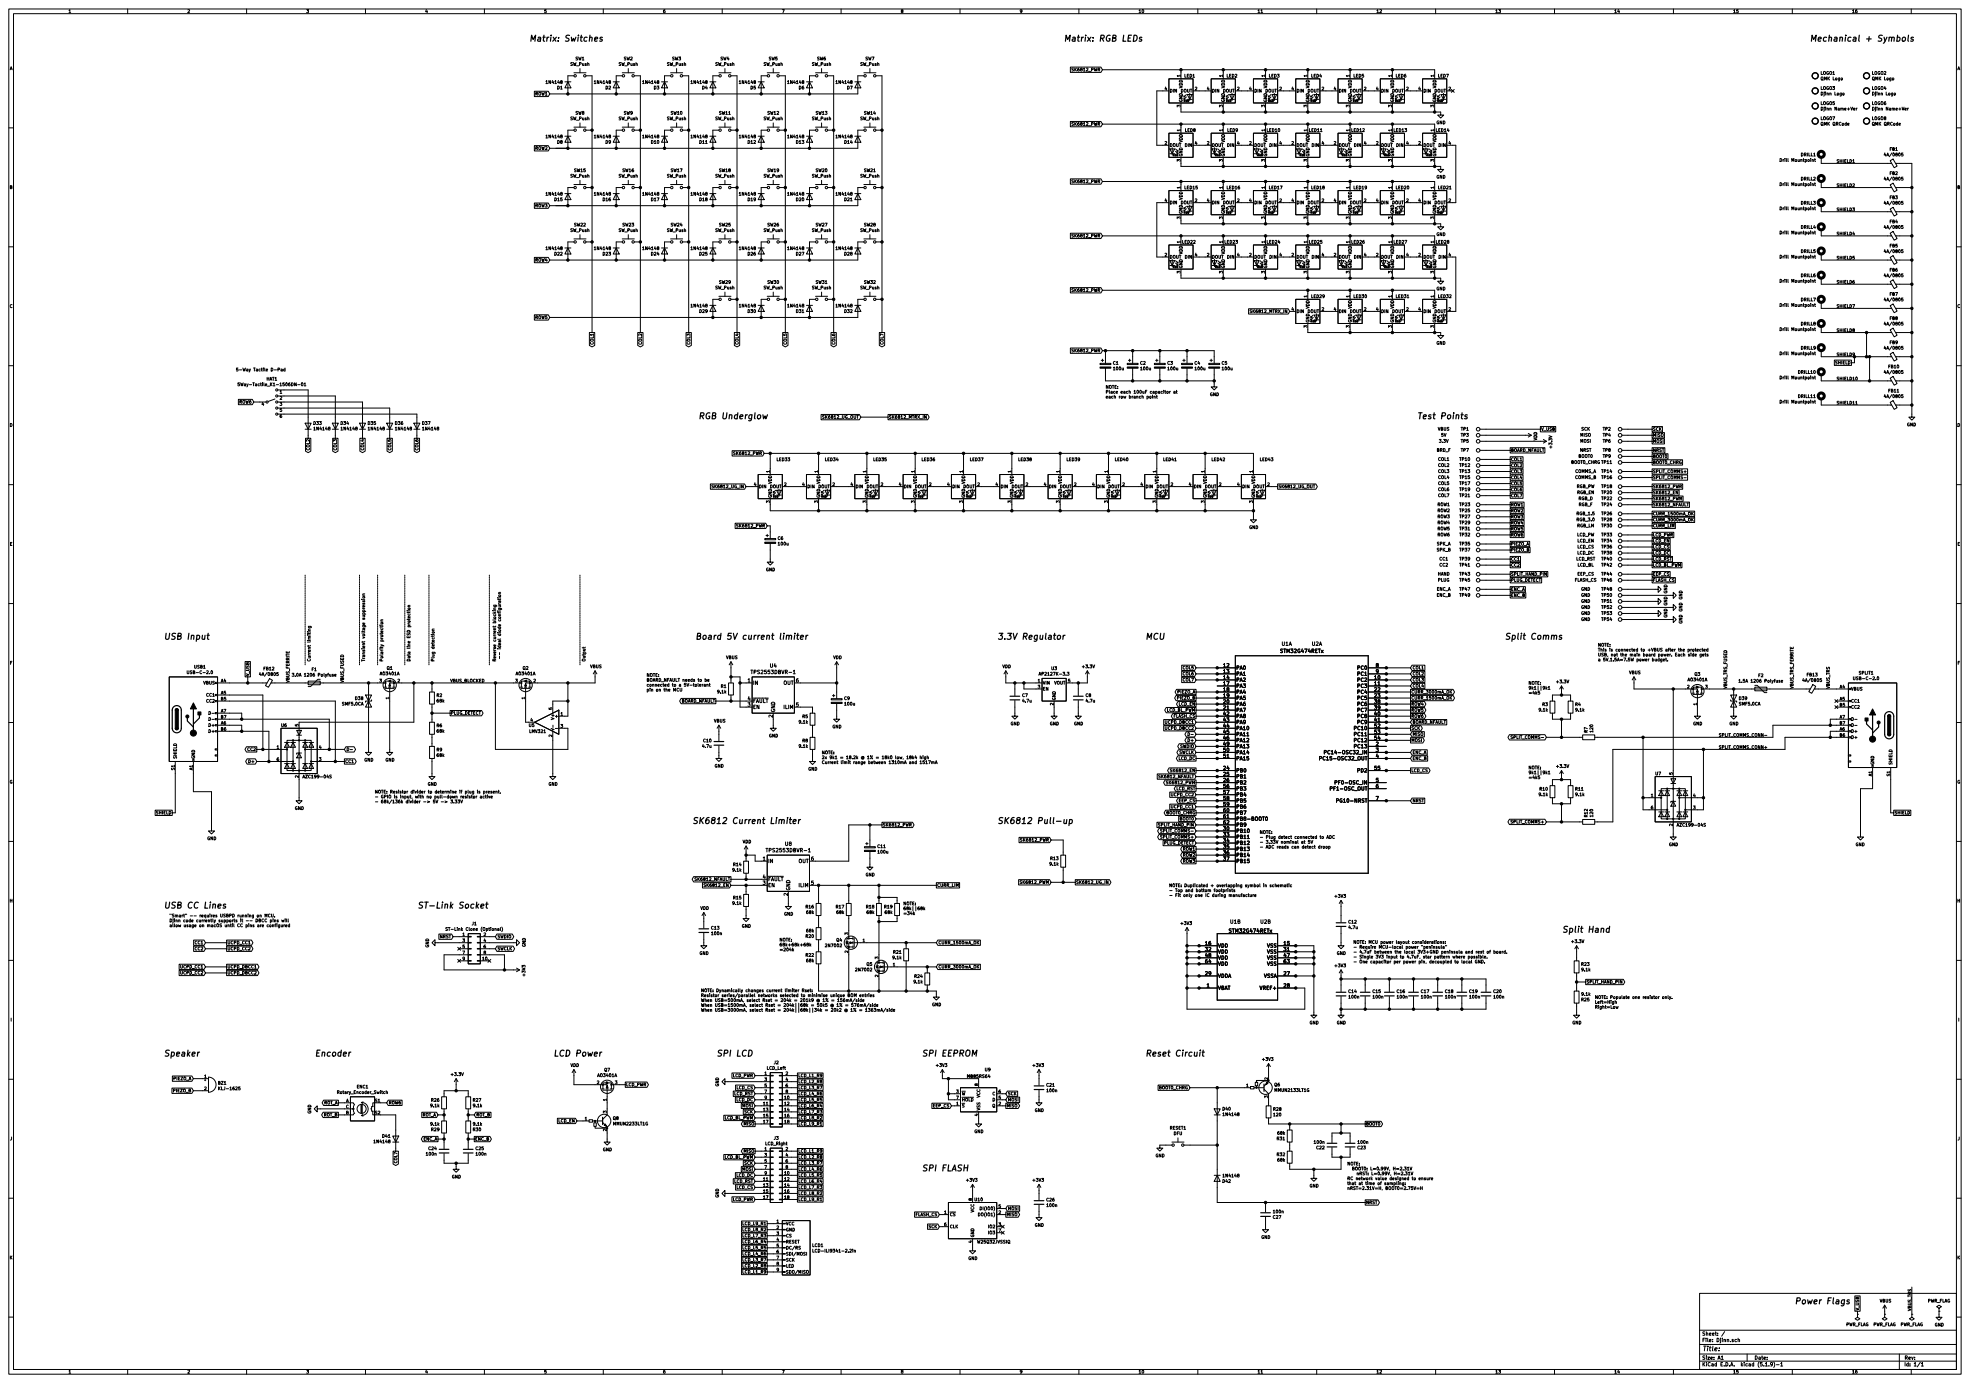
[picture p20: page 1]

LOGO6 Djinn Name+Ver LOGO5 Djinn Name+Ver

GND GND GND GND GND
LED14
RGB VDD

SHIELD11 SHIELD10 SHIELD9 SHIELD8 SHIELD7 SHIELD5 NOTE: Place each 100uF capacitor at

each row branch point

NOTE: 9k1||9k1 =4k5 Board 5V current limiter

NOTE: This is connected to +VBUS after the protected

USB, not the main board power. Each side gets
a 5V,1.5A=7.5W power budget.

NOTE: BOARD_NFAULT needs to be

connected to a 5V-tolerant pin on the MCU

Current limit range between 1310mA and 1517mA
GND

NOTE: 9k1||9k1 =4k5 ST-Link Socket

NOTE: Resistor divider to determine if plug is present.
- GPIO is input, with no pull-down resistor active

NOTE: - Plug detect connected to ADC

- 3.33V nominal at 5V
- ADC reads can detect droop

NOTE: Duplicated + overlapping symbol in schematic
- Top and bottom footprints
- Fit only one IC during manufacture

"Smart" -- requires USBPD running on MCU.
Djinn code currently supports it -- DBCC pins will
allow usage on macOS until CC pins are configured

NOTE: MCU power layout considerations:
- Require MCU-local power "peninsula"
- 4.7uF between the local 3V3+GND peninsula and rest of board.
- Single 3V3 input to 4.7uF, star pattern where possible.
- One capacitor per power pin, decoupled to local GND.

NOTE: Dynamically changes current limiter Rset:
Resistor series/parallel networks selected to minimise unique BOM entries
When USB=500mA, select Rset = 204k = 201k9 @ 1% = 156mA/side
When USB=1500mA, select Rset = 204k||68k = 50k5 @ 1% = 576mA/side
When USB=3000mA, select Rset = 204k||68k||34k = 20k2 @ 1% = 1363mA/side

NOTE: Populate one resistor only.
Left=High
Right=Low

BOOT0: L=0.99V, H=2.31V
nRST: L=0.99V, H=2.31V RC network value designed to ensure

that at time of sampling: nRST=2.31V=H, BOOT0=2.75V=H

File: Djinn.sch Sheet: /

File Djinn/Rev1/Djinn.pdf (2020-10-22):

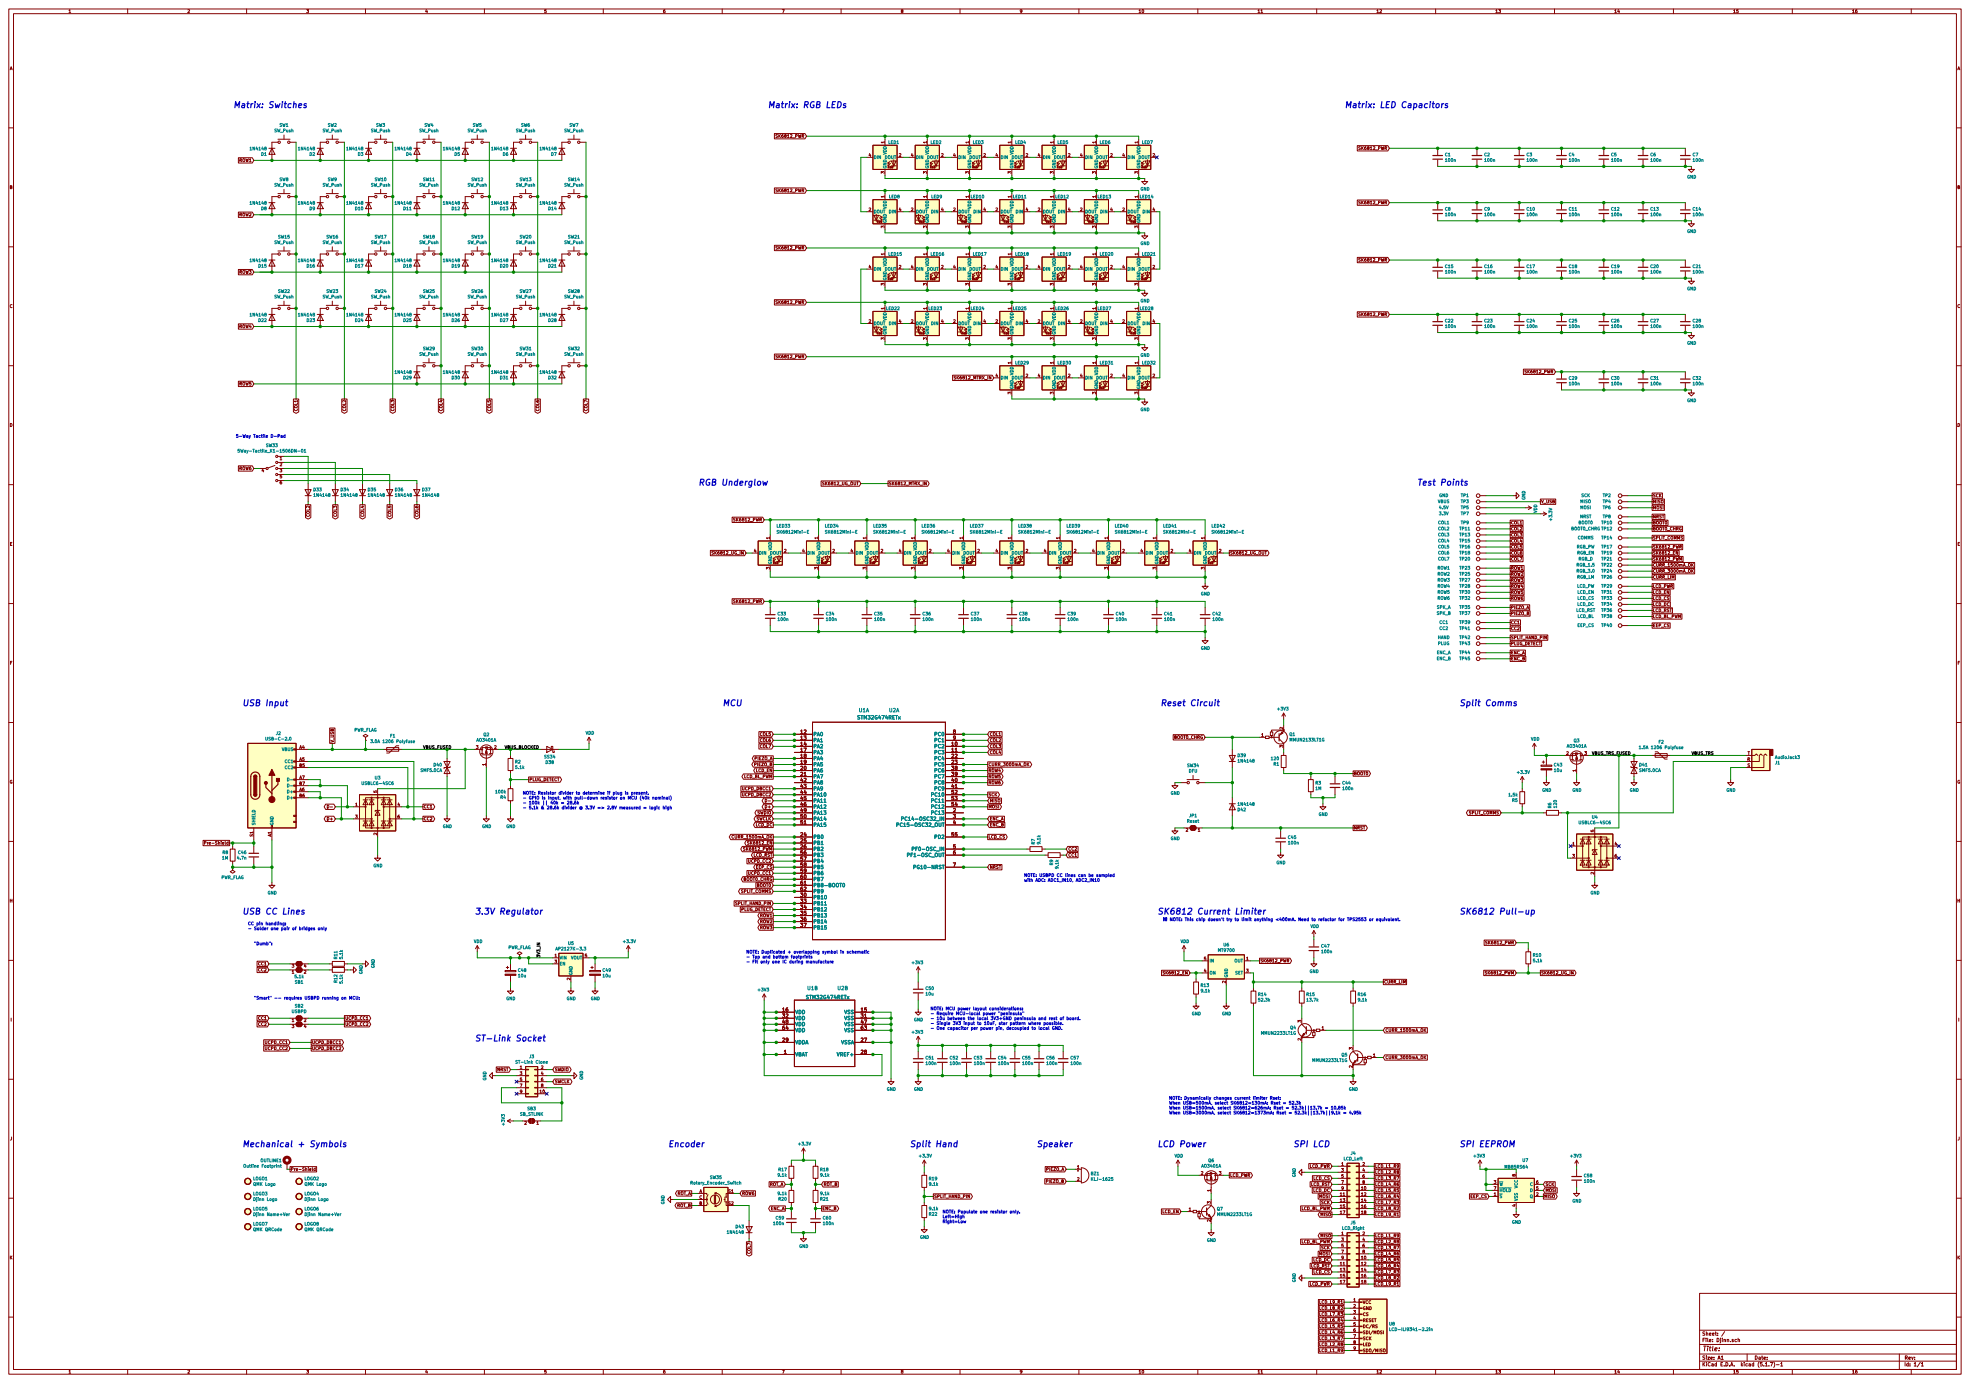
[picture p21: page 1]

NOTE: Resistor divider to determine if plug is present.
- GPIO is input, with pull-down resistor on MCU (40k nominal)
- 5.1k & 28.6k divider @ 3.3V => 2.8V measured = logic high

NOTE: USBPD CC lines can be sampled with ADC: ADC1_IN10, ADC2_IN10

CC pin handling:
- Solder one pair of bridges only

!!! NOTE: This chip doesn't try to limit anything <400mA. Need to refactor for TPS2553 or equivalent.

"Dumb": "Smart" -- requires USBPD running on MCU:

NOTE: Duplicated + overlapping symbol in schematic
- Top and bottom footprints
- Fit only one IC during manufacture

NOTE: MCU power layout considerations:
- Require MCU-local power "peninsula"
- 10u between the local 3V3+GND peninsula and rest of board.
- Single 3V3 input to 10uF, star pattern where possible.
- One capacitor per power pin, decoupled to local GND.

NOTE: Dynamically changes current limiter Rset: When USB=500mA, select SK6812=130mA: Rset = 52.3k When USB=1500mA, select SK6812=626mA: Rset = 52.3k||13.7k = 10.85k

When USB=3000mA, select SK6812=1373mA: Rset = 52.3k||13.7k||9.1k = 4.95k

NOTE: Populate one resistor only.
Left=High
Right=Low

File: Djinn.sch Sheet: /

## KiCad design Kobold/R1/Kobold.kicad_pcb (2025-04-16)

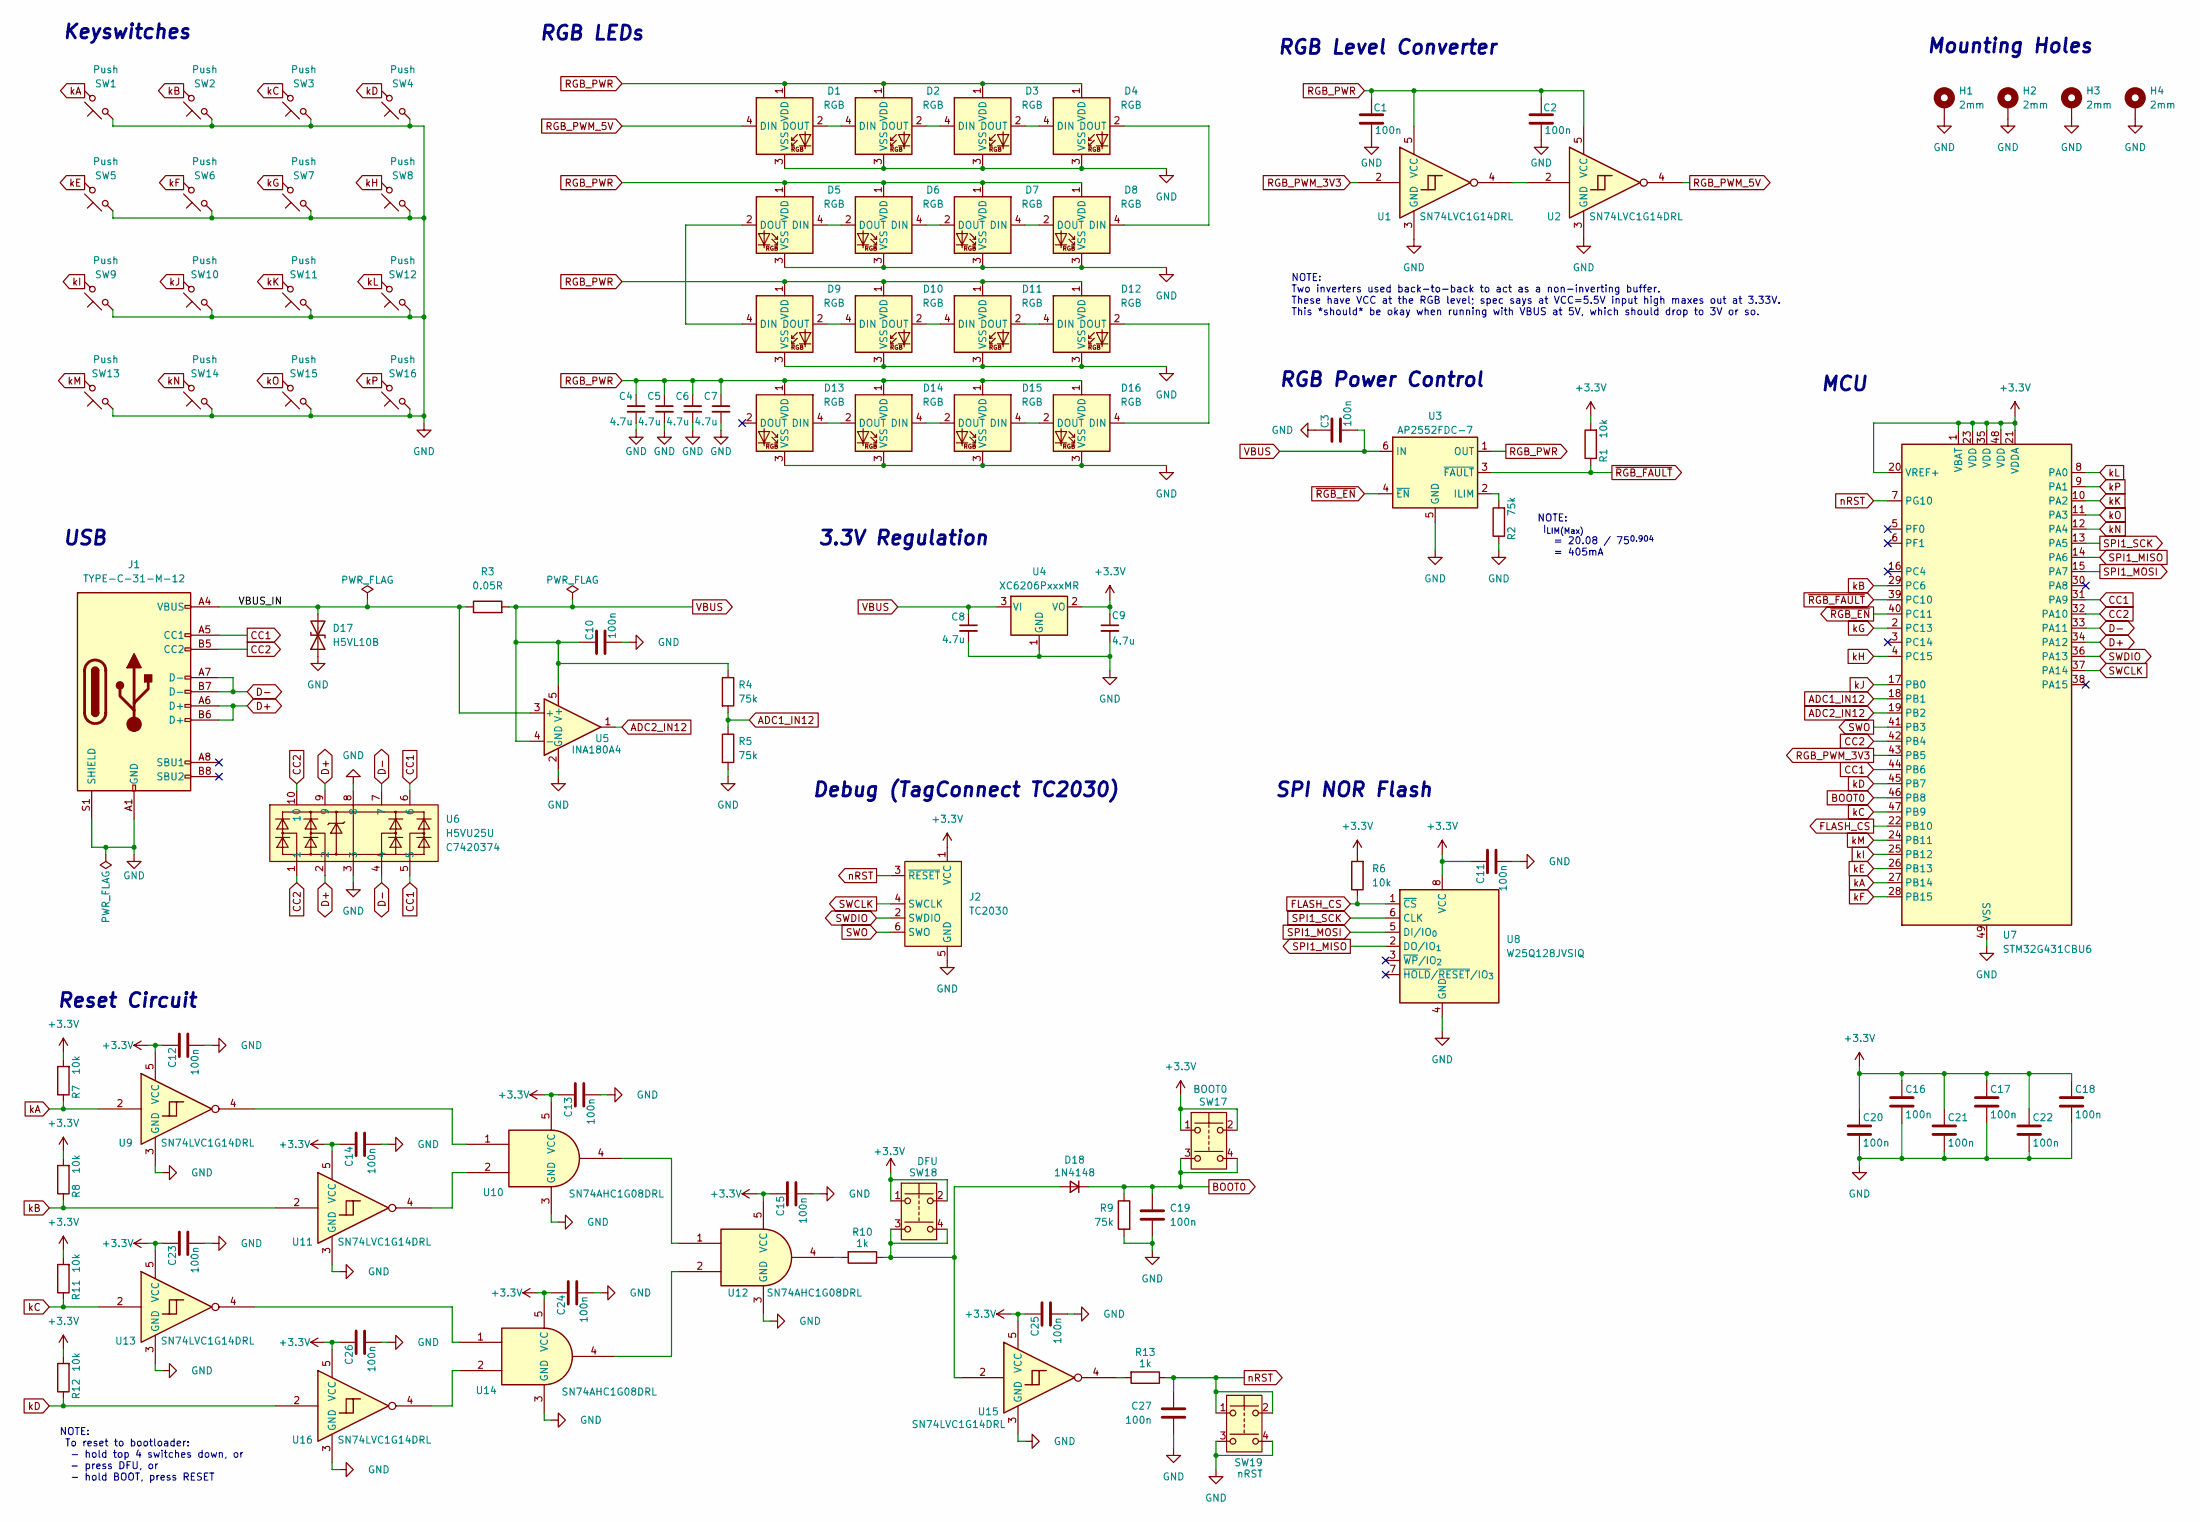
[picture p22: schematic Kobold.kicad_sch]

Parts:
C1, C2, C3, C10, C11, C12, C13, C14, C15, C16, C17, C18, C19, C20, C21, C22, C23, C24, C25, C26, C27: 100n; C_0402_1005Metric; LCSC C1525
C4, C5, C6, C7, C8, C9: 4.7u; C_0402_1005Metric; LCSC C23733
D1, D2, D3, D4, D9, D10, D11, D12: RGB; LED_choc_6028R; LCSC C5149201
D5, D6, D7, D8, D13, D14, D15, D16: RGB; LED_choc_6028R-ROT; LCSC C5149201
D17: H5VL10B; D_SOD-882; LCSC C7420372
D18: 1N4148; D_SOD-323; LCSC C2128
H1, H2, H3, H4: 2mm; MountingHole_2.2mm_M2_Pad
J1: TYPE-C-31-M-12; USB_C_Receptacle_HRO_TYPE-C-31-M-12; LCSC C165948
J2: TC2030; Tag-Connect_TC2030-IDC-FP_2x03_P1.27mm_Vertical
R1, R6, R7, R8, R11, R12: 10k; R_0402_1005Metric; LCSC C25744
R2, R4, R5, R9: 75k; R_0603_1608Metric; LCSC C23242
R3: 0.05R; R_1206_3216Metric; LCSC C912768
R10, R13: 1k; R_0402_1005Metric; LCSC C11702
SW1, SW2, SW3, SW4, SW5, SW6, SW7, SW8, SW9, SW10, SW11, SW12, SW13, SW14, SW15, SW16: Push; SW_choc_v1_HS_CPG135001S30_1u
SW17: BOOT0; SW-SMD_4P-L3.0-W2.6-P1.80-LS3.4-TL; LCSC C778132
SW18: DFU; SW-SMD_4P-L3.0-W2.6-P1.80-LS3.4-TL; LCSC C778132
SW19: nRST; SW-SMD_4P-L3.0-W2.6-P1.80-LS3.4-TL; LCSC C778132
U1, U2, U9, U11, U13, U15, U16: SN74LVC1G14DRL; SOT-553-5_L1.6-W1.2-P0.50-LS1.6-BL; LCSC C2682052
U3: AP2552FDC-7; WDFN-6_L2.0-W2.0-P0.65-BL-EP-1; LCSC C150475
U4: XC6206PxxxMR; SOT-23-3; LCSC C5446
U5: INA180A4; SOT-23-5_L3.0-W1.7-P0.95-LS2.8-BR; LCSC C188337
U6: H5VU25U; DFN2510-10_L2.5-W1.0-P0.50-BL; LCSC C7420374
U7: STM32G431CBU6; QFN-48-1EP_7x7mm_P0.5mm_EP5.6x5.6mm; LCSC C529356
U8: W25Q128JVSIQ; SOIC-8_5.3x5.3mm_P1.27mm; LCSC C97521
U10, U12, U14: SN74AHC1G08DRL; SOT-553-5_L1.6-W1.2-P0.50-LS1.6-BL; LCSC C352951

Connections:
+3.3V: C9.1, C11.1, C12.1, C13.1, C14.1, C15.1, C16.1, C17.1, C18.1, C20.1, C21.1, C22.1, C23.1, C24.1, C25.1, C26.1, J2.1 (VCC), R1.2, R6.2, R7.2, R8.2, R11.2, R12.2, SW17.1, SW17.2, SW18.1, SW18.2, U4.2 (VO), U7.1 (VBAT), U7.20 (VREF+), U7.21 (VDDA), U7.23 (VDD), U7.35 (VDD), U7.48 (VDD), U8.8 (VCC), U9.5 (VCC), U10.5 (VCC), U11.5 (VCC), U12.5 (VCC), U13.5 (VCC), U14.5 (VCC), U15.5 (VCC), U16.5 (VCC)
/VBUS_IN: D17.2 (A2), J1.A4 (VBUS), J1.A9 (VBUS), J1.B4 (VBUS), J1.B9 (VBUS), R3.1, U5.3 (+)
ADC1_IN12: R4.2, R5.1, U7.18 (PB1)
ADC2_IN12: U5.1, U7.19 (PB2)
BOOT0: C19.1, D18.1 (K), R9.1, SW17.3, SW17.4, U7.46 (PB8)
CC1: J1.A5 (CC1), U6.5, U6.6, U7.31 (PA9), U7.44 (PB6)
CC2: J1.B5 (CC2), U6.1, U6.10, U7.32 (PA10), U7.42 (PB4)
D+: J1.A6 (D+), J1.B6 (D+), U6.2, U6.9, U7.34 (PA12)
D-: J1.A7 (D-), J1.B7 (D-), U6.4, U6.7, U7.33 (PA11)
FLASH_CS: R6.1, U7.22 (PB10), U8.1 (~CS)
GND: C1.2, C2.2, C3.1, C4.2, C5.2, C6.2, C7.2, C8.2, C9.2, C10.2, C11.2, C12.2, C13.2, C14.2, C15.2, C16.2, C17.2, C18.2, C19.2, C20.2, C21.2, C22.2, C23.2, C24.2, C25.2, C26.2, C27.2, D1.3 (VSS), D2.3 (VSS), D3.3 (VSS), D4.3 (VSS), D5.3 (VSS), D6.3 (VSS), D7.3 (VSS), D8.3 (VSS), D9.3 (VSS), D10.3 (VSS), D11.3 (VSS), D12.3 (VSS), D13.3 (VSS), D14.3 (VSS), D15.3 (VSS), D16.3 (VSS), D17.1 (A1), H1.1, H2.1, H3.1, H4.1, J1.A1 (GND), J1.A12 (GND), J1.B1 (GND), J1.B12 (GND), J1.S1 (SHIELD), J2.5 (GND), R2.1, R5.2, R9.2, SW1.1, SW2.1, SW3.1, SW4.1, SW5.1, SW6.1, SW7.1, SW8.1, SW9.1, SW10.1, SW11.1, SW12.1, SW13.1, SW14.1, SW15.1, SW16.1, SW19.3, SW19.4, U1.3 (GND), U2.3 (GND), U3.5 (GND), U3.7 (EP), U4.1 (GND), U5.2 (GND), U6.3, U6.8, U7.49 (VSS), U8.4 (GND), U9.3 (GND), U10.3 (GND), U11.3 (GND), U12.3 (GND), U13.3 (GND), U14.3 (GND), U15.3 (GND), U16.3 (GND)
unnamed: D1.2 (DOUT), D2.4 (DIN)
unnamed: D2.2 (DOUT), D3.4 (DIN)
unnamed: D3.2 (DOUT), D4.4 (DIN)
unnamed: D4.2 (DOUT), D8.4 (DIN)
unnamed: D5.4 (DIN), D6.2 (DOUT)
unnamed: D5.2 (DOUT), D9.4 (DIN)
unnamed: D6.4 (DIN), D7.2 (DOUT)
unnamed: D7.4 (DIN), D8.2 (DOUT)
unnamed: D9.2 (DOUT), D10.4 (DIN)
unnamed: D10.2 (DOUT), D11.4 (DIN)
unnamed: D11.2 (DOUT), D12.4 (DIN)
unnamed: D12.2 (DOUT), D16.4 (DIN)
unnamed: D13.4 (DIN), D14.2 (DOUT)
unnamed: D14.4 (DIN), D15.2 (DOUT)
unnamed: D15.4 (DIN), D16.2 (DOUT)
unnamed: D18.2 (A), R10.1, SW18.3, SW18.4, U15.2
unnamed: R10.2, U12.4
unnamed: R13.2, U15.4
unnamed: U1.4, U2.2
unnamed: R2.2, U3.2 (ILIM)
unnamed: U9.4, U10.1
unnamed: U10.2, U11.4
unnamed: U10.4, U12.1
unnamed: U12.2, U14.4
unnamed: U13.4, U14.1
unnamed: U14.2, U16.4
RGB_PWM_3V3: U1.2, U7.43 (PB5)
RGB_PWM_5V: D1.4 (DIN), U2.4
RGB_PWR: C1.1, C2.1, C4.1, C5.1, C6.1, C7.1, D1.1 (VDD), D2.1 (VDD), D3.1 (VDD), D4.1 (VDD), D5.1 (VDD), D6.1 (VDD), D7.1 (VDD), D8.1 (VDD), D9.1 (VDD), D10.1 (VDD), D11.1 (VDD), D12.1 (VDD), D13.1 (VDD), D14.1 (VDD), D15.1 (VDD), D16.1 (VDD), U1.5 (VCC), U2.5 (VCC), U3.1 (OUT)
SPI1_MISO: U7.14 (PA6), U8.2 (DO/IO_{1})
SPI1_MOSI: U7.15 (PA7), U8.5 (DI/IO_{0})
SPI1_SCK: U7.13 (PA5), U8.6 (CLK)
SWCLK: J2.4 (SWCLK), U7.37 (PA14)
SWDIO: J2.2 (SWDIO), U7.36 (PA13)
SWO: J2.6 (SWO), U7.41 (PB3)
VBUS: C3.2, C8.1, C10.1, R3.2, R4.1, U3.6 (IN), U4.3 (VI), U5.4 (-), U5.5 (V+)
kA: R7.1, SW1.2, U7.27 (PB14), U9.2
kB: R8.1, SW2.2, U7.29 (PC6), U11.2
kC: R11.1, SW3.2, U7.47 (PB9), U13.2
kD: R12.1, SW4.2, U7.45 (PB7), U16.2
kE: SW5.2, U7.26 (PB13)
kF: SW6.2, U7.28 (PB15)
kG: SW7.2, U7.2 (PC13)
kH: SW8.2, U7.4 (PC15)
kI: SW9.2, U7.25 (PB12)
kJ: SW10.2, U7.17 (PB0)
kK: SW11.2, U7.10 (PA2)
kL: SW12.2, U7.8 (PA0)
kM: SW13.2, U7.24 (PB11)
kN: SW14.2, U7.12 (PA4)
kO: SW15.2, U7.11 (PA3)
kP: SW16.2, U7.9 (PA1)
nRST: C27.1, J2.3 (~RESET), R13.1, SW19.1, SW19.2, U7.7 (PG10)
~RGB_EN: U3.4 (~EN), U7.40 (PC11)
~RGB_FAULT: R1.1, U3.3 (~FAULT), U7.39 (PC10)

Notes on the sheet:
NOTE: I_{LIM(Max)} = 20.08 / 75^{0.904} = 405mA
SPI NOR Flash
Reset Circuit
MCU
RGB Power Control
3.3V Regulation
RGB Level Converter
RGB LEDs
Mounting Holes
USB
NOTE: To reset to bootloader: - hold top 4 switches down, or - press DFU, or - hold BOOT, press RESET
Keyswitches
Debug (TagConnect TC2030)
NOTE: Two inverters used back-to-back to act as a non-inverting buffer. These have VCC at the RGB level; spec says at VCC=5.5V input high maxes out at 3.33V. This *should* be okay when running with VBUS at 5V, which should drop to 3V or so.

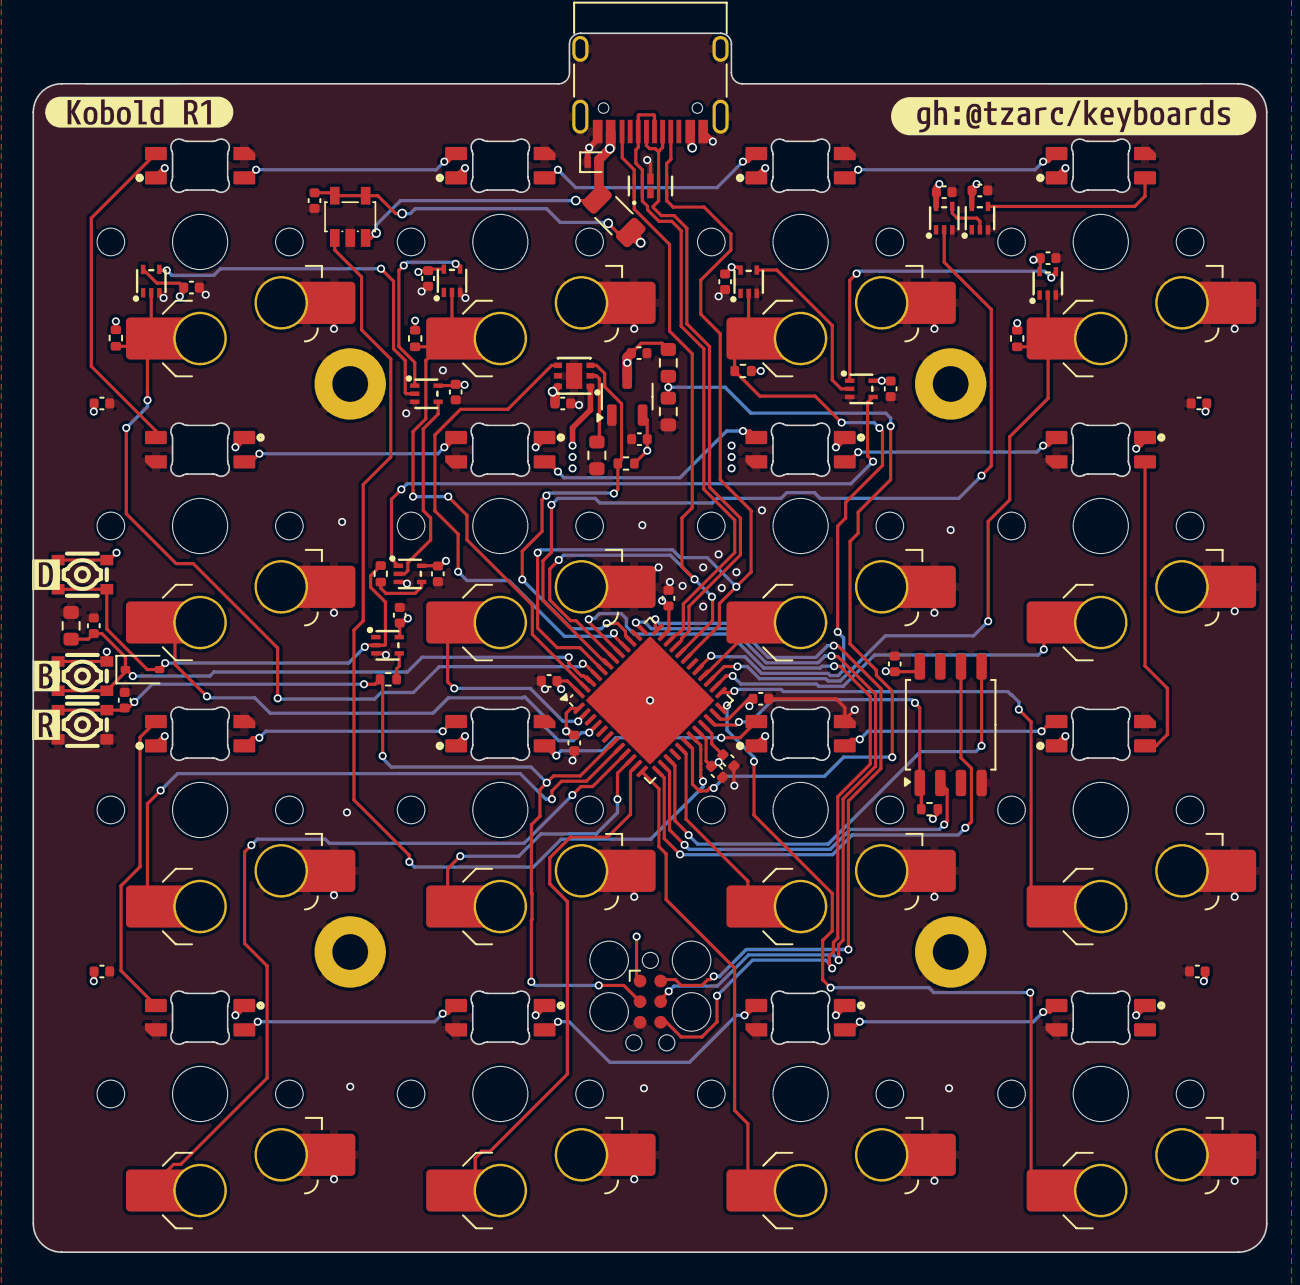
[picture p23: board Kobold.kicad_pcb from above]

Board: 4 copper layers, 76.0 x 75.1 mm, 104 parts (0 on the bottom side), 66 nets.

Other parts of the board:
kibuzzard-677E65CD: G***; kibuzzard-677E65CD
kibuzzard-677E65D8: G***; kibuzzard-677E65D8
kibuzzard-677E65DF: G***; kibuzzard-677E65DF
kibuzzard-677E6627: G***; kibuzzard-677E6627
kibuzzard-677E6634: G***; kibuzzard-677E6634

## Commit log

2020-10-25 Add Rev1 BOM document.
2020-10-25 Add fasteners to the BOM.
2020-10-25 Added some notes to the BOM.
2021-04-11 Add Rev2a.
    [Djinn-B_Cu.gbr, Djinn-B_Mask.gbr, Djinn-B_Paste.gbr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]
2021-04-11 Generate some more DXF's.
    [Djinn-B_Cu.gbr, Djinn-B_Mask.gbr, Djinn-B_Paste.gbr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]
2021-04-12 Add note about JLC randomly charging extra.
2021-05-12 Add STLs for Rev2a.
    [Djinn_BottomSpacer_3mm.stl, Djinn_TopSpacer_3.5mm.stl]
2021-05-27 Fixup BOM -- add LCD, fixup F931C107KCC 100uF cap.
2021-11-23 Alternate ESD protection diode.
2024-02-17 Consolidate keyboards into a single repository.
    [Board-DjinnBase-B_Cu.gbr, Board-DjinnBase-B_Mask.gbr, Board-DjinnBase-B_Paste.gbr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]
2025-04-16 Add Kobold.
    [BOM-Kobold.csv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]
